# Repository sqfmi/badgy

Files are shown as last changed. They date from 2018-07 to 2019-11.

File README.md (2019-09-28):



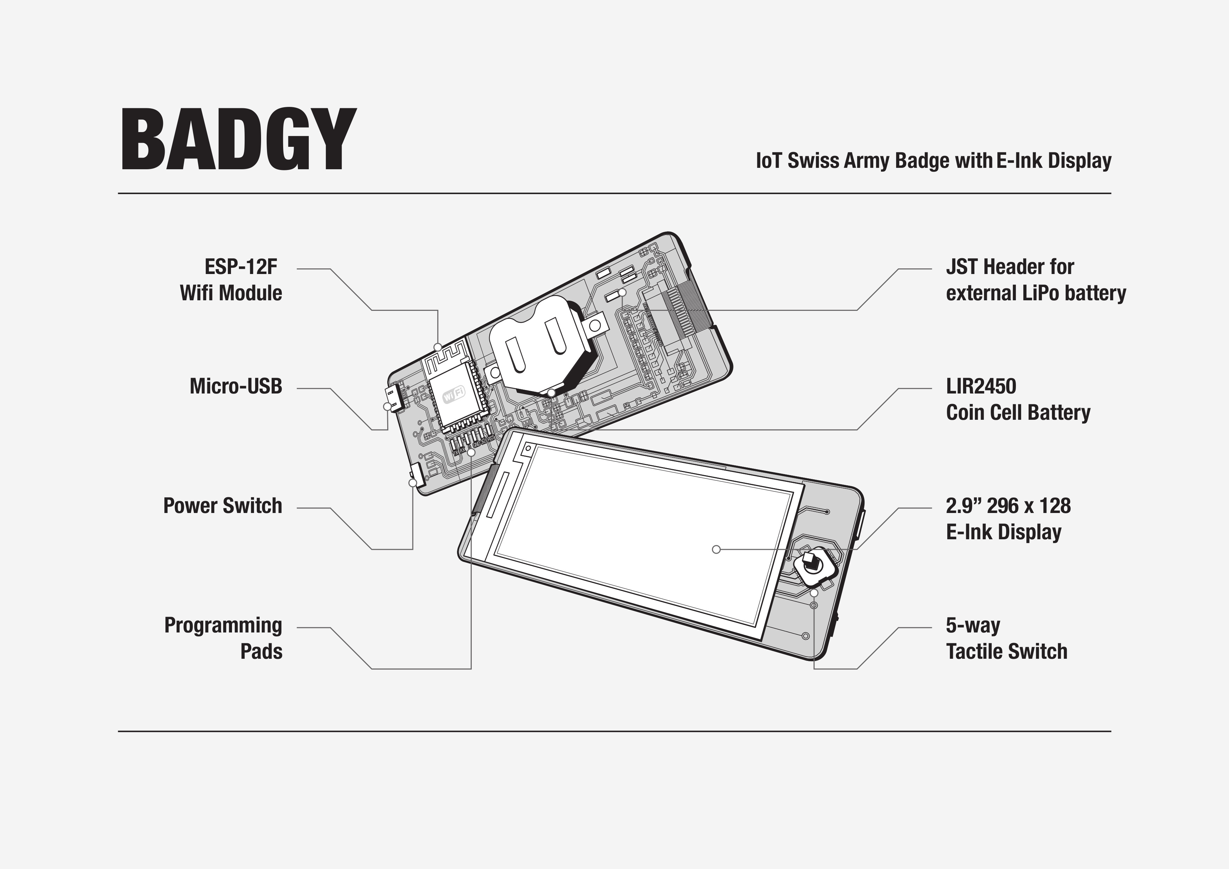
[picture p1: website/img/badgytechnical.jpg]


# Know Your Badgy

Since launching the first revision of Badgy, we have made various updates and fixes to the hardware and design. Refer to the diagram below to know which revision of Badgy you have. This is helpful for getting started and troubleshooting.

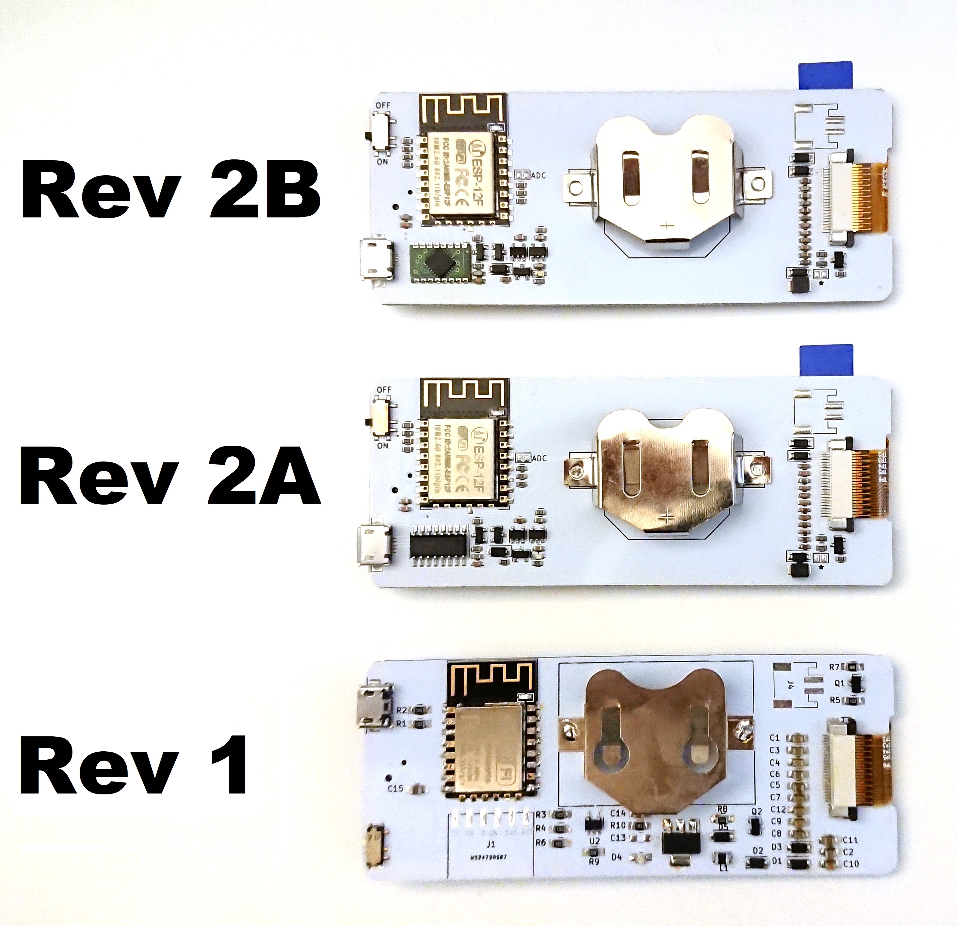
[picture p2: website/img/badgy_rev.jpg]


### Rev 2C

This is the latest revision of Badgy (September 2019) with a new display that supports 2-bit 4 color grayscale (Black/Dark Gray/Light Gray/White). It can be uniquely identified by the closed solder jumper on the back marked with the asterisk \*. It also has a green tab on the screen protector film.

### Rev 2B

This revision of Badgy (May 2019) can be uniquley identified by the small green PCB on the bottom left corner. It supports programming over USB (updated from CH340 to CP2104, woohoo!) and WiFi OTA. It fixes the battery issue with Rev 2A.

### Rev 2A

This revision of Badgy adds USB programming capability with the CH340 USB-UART controller. It also has two additional jumper pads: 1) ADC broken out if you choose to measure the battery voltage 2) jumper pad for driving other E-ink displays (e.g. 2.13" flexible E-ink). This version has a hardware bug that causes Badgy to not work on battery power, full description with hacks/fixes described here https://github.com/sqfmi/badgy/issues/20.

### Rev 1

This is the original and first revision of Badgy. It only supports firmware uploading via WiFi OTA, but the programming pads are broken out so you could also use your own USB-Serial adapter.

# Getting Started

By default your Badgy displays the welcome message when powered on. To upload new firmware, you can simply connect via USB **(Rev 2A/2B)**, or to your WiFi network **(Rev 1/2A/2B)**. You will also need a **LIR2450** rechargeable coin cell battery if you wish to run on battery power only.

**WARNING: Make sure you are using a rechargeable battery (LIR2450 coin cell or 1S LiPo). Other batteries such as the CR2450 or CR2032 are undervoltage (3.0V) and will not work. The battery charging IC also does not have reverse polarity protection! Check the polarity before inserting the battery**

## Over USB (for Rev 2A & Rev 2B)
1. Download and install the latest version of Arduino IDE
2. Install board support for the ESP8266 using the Arduino Board Manager using instructions found [here](https://github.com/esp8266/Arduino#installing-with-boards-manager).
3. If you are using a windows machine then you need to add support for the CP201X by installing drivers from [here](https://www.silabs.com/community/interface/knowledge-base.entry.html/2016/12/30/downloading_cp210xd-ek07).
4. The USB-Serial device should show up on the list of ports (e.g. COM8, /dev/cu.\* , /dev/tty.\*).  If you don't see it then it is possible that you need to install the drivers for CP2104 on your system.
5. From Tools -> Board choose "NodeMCU 1.0 (ESP-12E Module)".
6. Compile and upload one of our code samples, or create your own!  See the 'compiling' section below for some details.

Note that if the ESP chip is in a deep sleep then it will not automatically respond to the upload request and you may see something like "error: espcomm open failed" when trying to upload.  A manual restart of the ESP chip, using the power slide button, just prior to upload gives you a small window of time to upload.

## Over WiFi
1. Power your Badgy through USB or a rechargeable battery, or both. Make sure the power switch is in the off position (up)
2. Hold down the center button and slide the power switch on (down). **Note: On older firmware versions it is not necessary to hold down the center button and OTA is on by default**
3. The screen should now update letting you know to connect to the "Badgy AP" network. You can now let go of the center button
4. Using your mobile phone, connect to the "Badgy AP" WiFi network
5. Follow the captive portal instructions to select your desired WiFi connection
6. Once connected, Badgy is ready to receive new firmware! Go to http://*YOUR_IP_ADDRESS*:8888/update to upload your new firmware
7. WiFi credentials are automatically saved onboard, your Badgy will automatically connect to your selected network the next time you perform an update

Check out the examples folders for various code samples, we're constantly adding more!

## Compiling examples
The readme files within the example directories contain specific library and version information for that example.   At a minimum though you should consider installing the following libraries as they are very useful and/or necessary for any real functionality.

1. GxEPD library: you can find the repo [here](https://github.com/ZinggJM/GxEPD).
2. AdaFruit GFX library: installation instructions available [here](https://learn.adafruit.com/adafruit-gfx-graphics-library/overview).
3. WifiManager library: you can find the repo [here](https://github.com/tzapu/WiFiManager).  You can also find this in the Library Manager under 'WiFiManager by tzapu'.
4. Time library: you can find the repo [here](https://github.com/PaulStoffregen/Time).  
5. ArduinoJson library: you can find the repo [here](https://github.com/bblanchon/ArduinoJson). You can also find this in the Library Manager under 'ArduinoJson by Benoit Blanchon'.   Make sure that you install a 5.x version since some of the examples require that.

## Autoreset
Some users have reported that Badgy doesn't automatically reset after uploading a new sketch via USB; this appears to be an issue with the ESP8266 Arduino library v2.5.0+. You can either toggle the power switch to reset, or downgrade to v2.4.2. This issue does not affect the operation of Badgy

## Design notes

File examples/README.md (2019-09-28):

## Setup
- Install Arduino IDE https://www.arduino.cc/en/Main/Software
- Add ESP8266 Arduino Core using the Boards Manager https://github.com/esp8266/Arduino#installing-with-boards-manager
- Install the following libraries for the various examples
    - Adafruit GFX library https://github.com/adafruit/Adafruit-GFX-Library
    - GxEPD v3.x library https://github.com/ZinggJM/GxEPD
    - ArduinoJSON v5.x library https://github.com/bblanchon/ArduinoJson
    - WiFi Manager library https://github.com/tzapu/WiFiManager
    - Time v1.5 https://github.com/michaelmargolis/arduino_time
    - WebSockets https://github.com/Links2004/arduinoWebSockets
- When compiling the sketch in the Arduino IDE, choose **Tools** > **Board** > **NodeMCU 1.0 (ESP-12E Module)**    

## Uploading Your Own Firmware

### Over USB (For Rev 2A/2B)
1. Once the right board and port is selected, simply click upload and your sketch will be uploaded automatically. Make sure the power switch is on (down), and you should see the the blue LED on the ESP-12F module flsahing.

### Over Wifi (For Rev 1/2A/2B/2C)
1. In the Arduino IDE, go to *Sketch* -> *Export compiled Binary* to create your firmware binary `*.bin`
2. Slide the power switch off (up), hold the center button and slide the power switch on (down) at the same time. Your Badgy should now be in OTA mode.
3. Go to http://*BADGY_IP_ADDRESS*:8888/update to upload your new `*.bin` file
4. Badgy will now restart with your new firmware
### Note: If your new firmware does not include the WiFi and OTA code, you will no longer be able to update over WiFi!

## Converting Your Own Image
Badgy has a 296x128 black & white e-paper display, you can upload your own bitmap image.
1. Go to http://javl.github.io/image2cpp/ and upload your own image file
2. Resize the image so that it is within the dimensions of the display (works best if dimensions are multiples of 8 e.g. 72x64)
3. Select **Arduino code** under **Code output format** and click the **Generate code** button
4. Copy and paste the output into your code; you can create a new header file (e.g. myimage.h) or simply replace the ```hello.h``` file in the Hello example. Remember to include the file in your main sketch.
5. The method ```display.drawBitmap(image, 0, 0, 296, 128, GxEPD_WHITE);``` draws the bitmap on the screen. The parameters are in the following order: image byte array, x, y, width, height, and background color. Call ```display.update()``` after to draw the new image.

## Restoring To Default Firmware
1. Download the default firmware [badgy.bin](https://github.com/sqfmi/badgy/raw/master/examples/badgy.bin)
2. Slide the power switch off (up), hold the center button and slide the power switch on (down) at the same time. Your Badgy should now be in OTA mode.
3. Go to http://*BADGY_IP_ADDRESS*:8888/update and upload `badgy.bin`
4. Badgy will now restart with the default firmware
5. You can also do this over USB following the instructions from above

## Using MicroPython with Badgy
Check out our [badgy-python repo](https://github.com/sqfmi/badgy-python)

## Manual Flashing / Recovery (For Rev 1)
* If for some reason your code is crashing and OTA updates isn't working, or if you prefer uploading over serial, you can manually flash the firmware using the programming pads on the PCB. Using a USB-Serial adapter (e.g. FTDI), connect the pins to the pads like so:
```
WARNING: ALWAYS DISCONNECT OTHER POWER SOURCES (E.G. USB/BATTERY) BEFORE CONNECTING SERIAL ADAPTER TO THE PROGRAMMING PADS.
WARNING: AVOID CONDUCTIVE CONTACT (E.G. METALS/LIQUIDS) ON THE EXPOSED PADS TO PREVENT DAMAGE
+------------+-----------+
| USB-Serial | Badgy     |
+------------+-----------+
| RX        =>    TX     |
| TX        =>    RX     |
| GND       =>    0      |
| GND       =>    GND    |
| 3V3       =>    3V3    |
| NC        =>    RST    |
+------------+-----------+
```
The blue LED on Badgy should start blinking during upload. You can use the Arduino IDE or [esptool](https://github.com/espressif/esptool) to flash your firmware.

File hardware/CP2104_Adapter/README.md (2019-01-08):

This is an adapter board to replace the CH340C with a CP2104. We recommend 1.0mm PCB thickness or less.

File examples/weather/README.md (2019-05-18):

# Weather Station

This code sample demonstrates a simple weather station that displays the current & forecasted weather using the [openweathermap](https://openweathermap.org) APIs.

Note that because this example puts the ESP into a deep sleep if you want to reprogram it via the USB then you have to manually stop and restart it using the slider switch at the moment just prior to the upload starting.

## Required Libraries
- See the base required libraries in the root Readme for this repository
- GxEPD 2.x
- ArduinJSON 5.x
- Time 1.5.0 - You can find the repo [here] (https://github.com/PaulStoffregen/Time)).  

## Instructions
- Download code sample and required libraries, and compile/upload in the Arduino IDE (1.8.5)
- Sometimes the API will return an error if the service is unavailable, simply restart Badgy to try again

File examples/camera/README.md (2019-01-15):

# Badgy Camera

<p align="center">
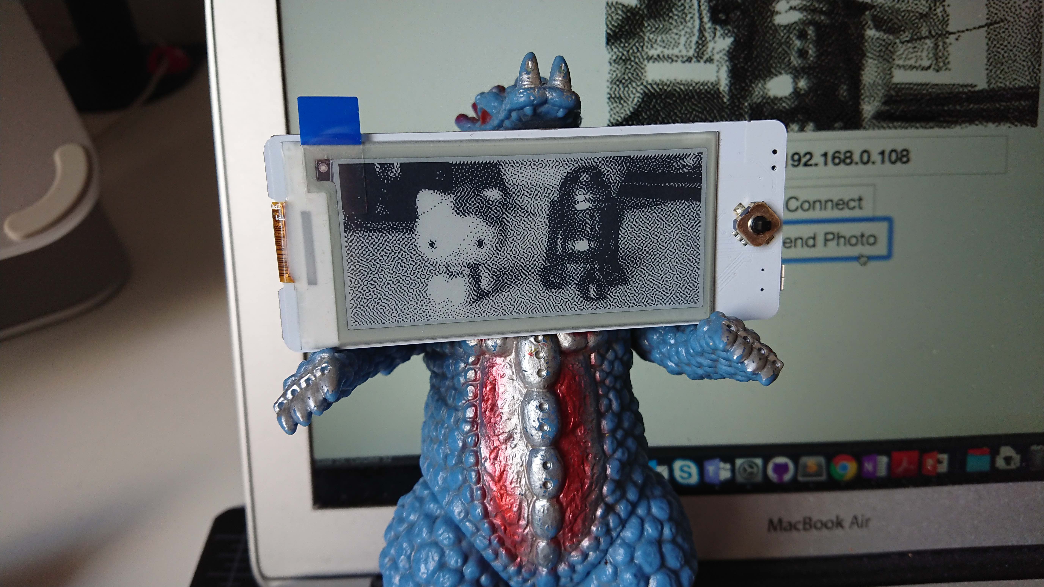
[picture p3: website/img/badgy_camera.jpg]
	
</p>

This code sample demonstrates display photos on Badgy captured through the webcam. Photo on the canvas is dithered and converted to a byte stream, then sent to Badgy over WebSocket. 

## Instructions
1. Turn on Badgy and wait for it to connect, note the IP address displayed.
2. Open `badgy-camera.html` using Chrome. The browswer will prompt you for camera permissions, click "allow".
3. Enter the IP address and click connect
4. Click "Send Photo" to capture and send the photo to Badgy

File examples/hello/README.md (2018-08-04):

# Hello Name Badge

<p align="center">
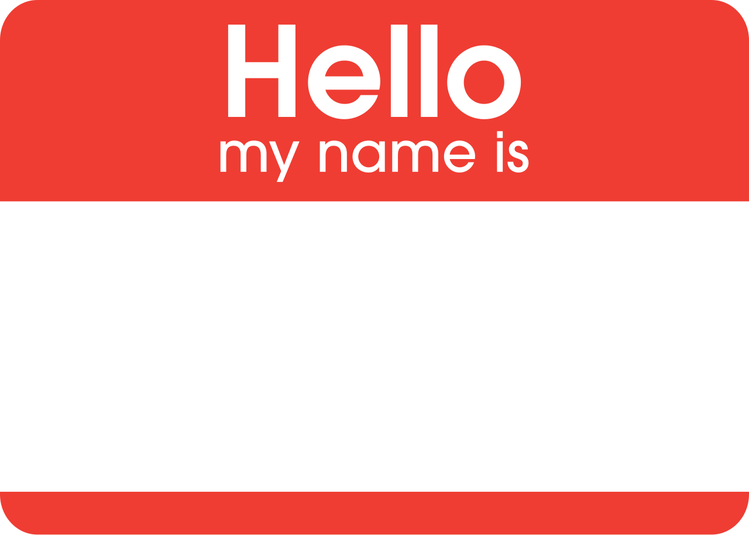
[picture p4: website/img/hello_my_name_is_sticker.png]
	
</p>
<p align="center">
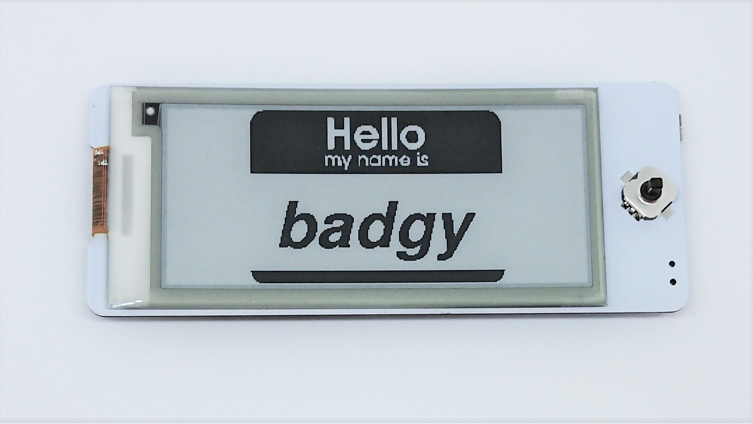
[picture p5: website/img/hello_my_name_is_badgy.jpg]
	
</p>

This code sample demonstrates displaying a "Hello my name is" badge on Badgy. The background image and is converted to a byte array from a PNG file and is stored in `hello.h`. The name is stored in a char array `const char* name = "badgy"` which can be changed to any text. It may be required to tweak the cursor location and font size in `showHello()` to perfectly position the text.

Power saving features are not enabled in this code sample and Badgy stays fully on. To conserve power, simply turn off Badgy as the e-paper display does not require power to maintain the displayed image.

## Instructions
- Download code sample & required libraries, and compile/upload in the Arduino IDE (1.8.5)
or
- Download the pre-compiled binary [hello.bin](https://github.com/sqfmi/badgy/raw/master/examples/hello/hello.bin) and upload using OTA

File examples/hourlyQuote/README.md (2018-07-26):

# Hourly Random Quote

This code sample demonstrates parsing JSON data from an API endpoint, as well as **deep sleep mode** for conserving power. To enter OTA mode, hold down **center** when powering on Badgy until the IP address is displayed. The code performs the following steps:

## Operation
1. Connect to WiFi on boot
2. If the **center** button is pressed, go into OTA mode (hold button till screen updates)
3. Otherwise, perform an `HTTP GET` request to the random quote API endpoint
4. Parse the returned JSON and display the quote
5. Enter deep sleep for approxmiately one hour
6. The sleep time can be modified at **line 59** in microseconds e.g. 60e6 = 60 seconds

## Instructions
- Download code sample and required libraries, and compile/upload in the Arduino IDE (1.8.5)
- Download the pre-compiled binary [hourlyQuote.bin](https://github.com/sqfmi/badgy/raw/master/examples/hourlyQuote/hourlyQuote.bin) and upload using OTA

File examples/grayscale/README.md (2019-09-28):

# Badgy Grayscale Demo

This code sample demonstrates displaying a 2-bit grayscale image (Black/Dark Gray/Light Gray/White). The image is converted to a byte array using the [Image2Lcd](https://www.waveshare.com/wiki/File:Image2Lcd.7z) tool.

<p align="center">
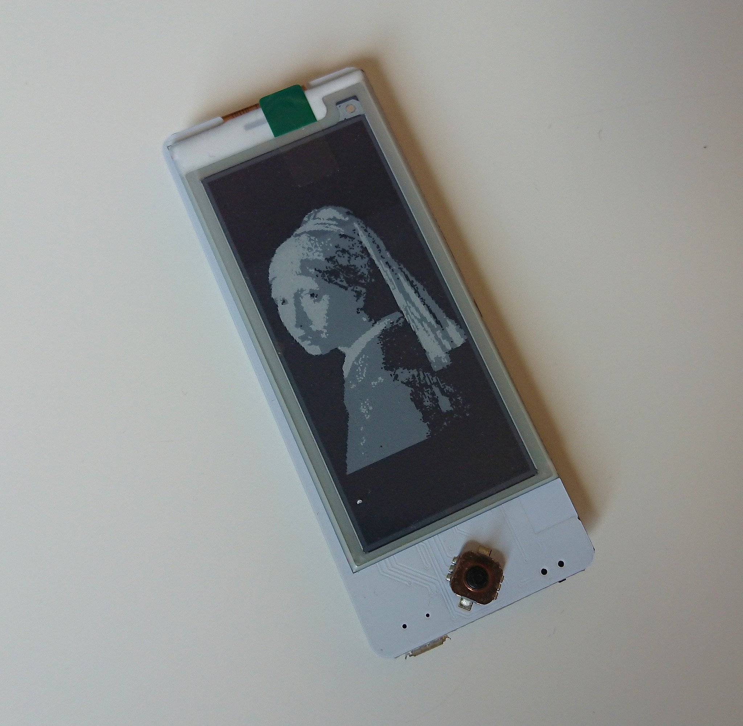
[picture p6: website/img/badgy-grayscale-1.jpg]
	
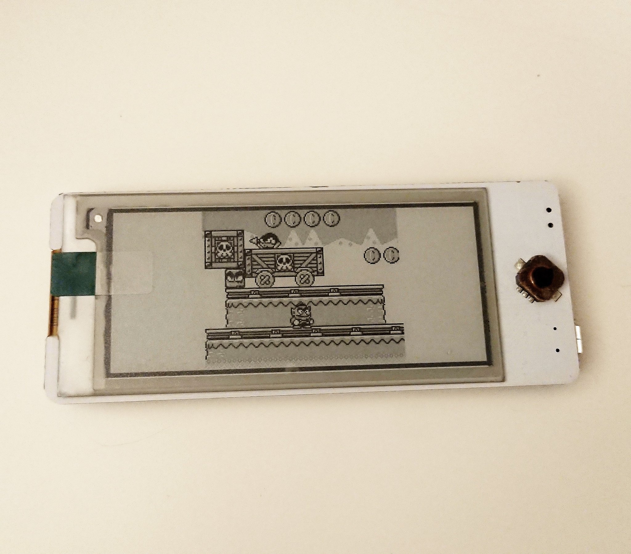
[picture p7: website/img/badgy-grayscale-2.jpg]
  
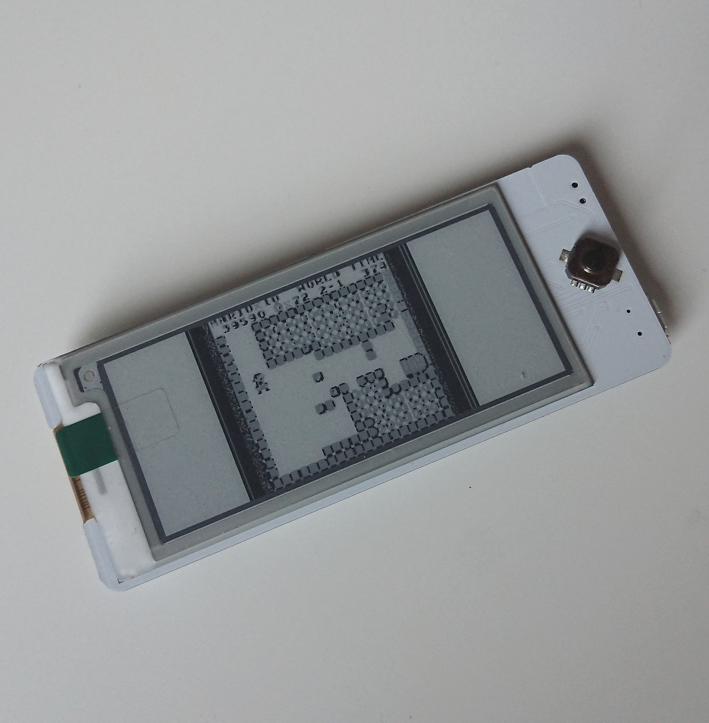
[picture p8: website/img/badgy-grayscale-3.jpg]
  
</p>

The following settings were used to generate the example images:

* Output file type: C array
* Scan mode: Vertical scan
*	BitsPixel: 16 Color
*	Max Width: 296
*	Max Height: 128
*	Scan Right to Left: Checked
*	Reverse Color: Checked
*	Mirroring: Normal

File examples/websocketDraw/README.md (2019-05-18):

# WebSocket Draw

<p align="center">
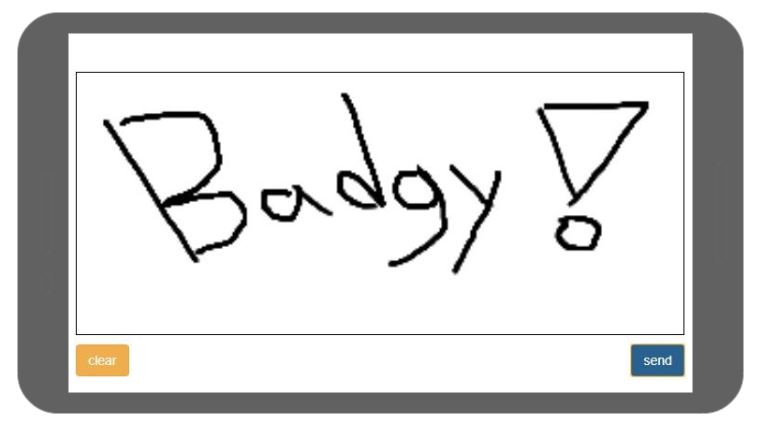
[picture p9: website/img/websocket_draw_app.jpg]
	
</p>
<p align="center">
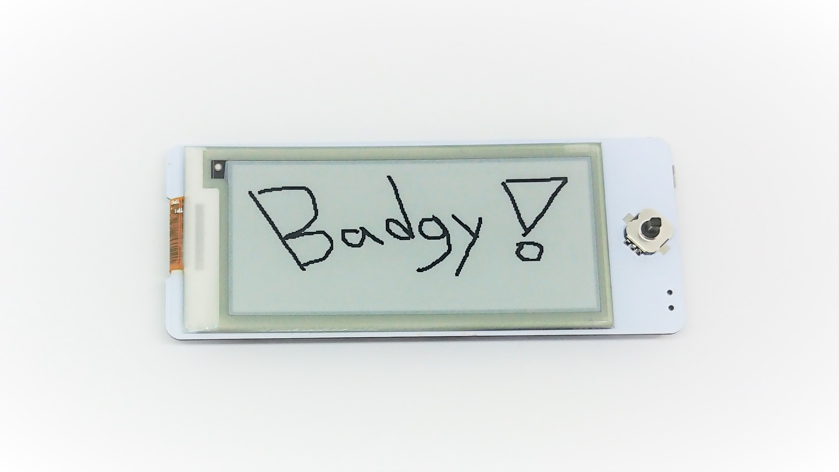
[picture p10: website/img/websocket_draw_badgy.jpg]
	
</p>

This code sample demonstrates drawing images on Badgy. Drawing done on the canvas is converted to a byte stream and sent to Badgy over WebSocket. 

## Required Libraries
- See the base required libraries in the root Readme for this repository
- Websocket server and client library found [here] (https://github.com/Links2004/arduinoWebSockets).
- ArduinJSON 5.x
- Time 1.5.0

## Instructions
1. Turn on Badgy and wait for it to connect, note the IP address displayed.
2. Edit `index.html` **line 58** and replace the IP address with Badgy's IP address e.g. `ws://192.168.0.113:81`.
3. Open `index.html` using Chrome or host it on a local server and open it on a mobile phone.
4. Draw on the canvas (using mouse or touch) and press **send**, your image should then appear on Badgy.
5. To clear the display, press **clear**

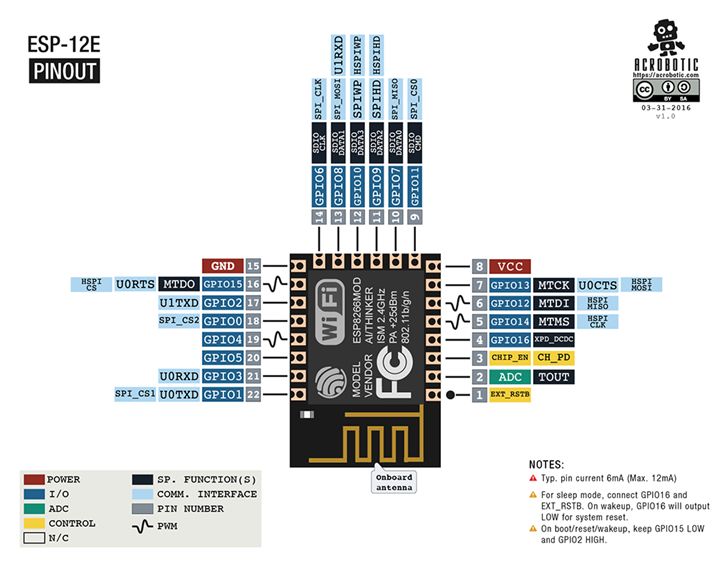
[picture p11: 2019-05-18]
hardware/ESP8266-12E.jpg

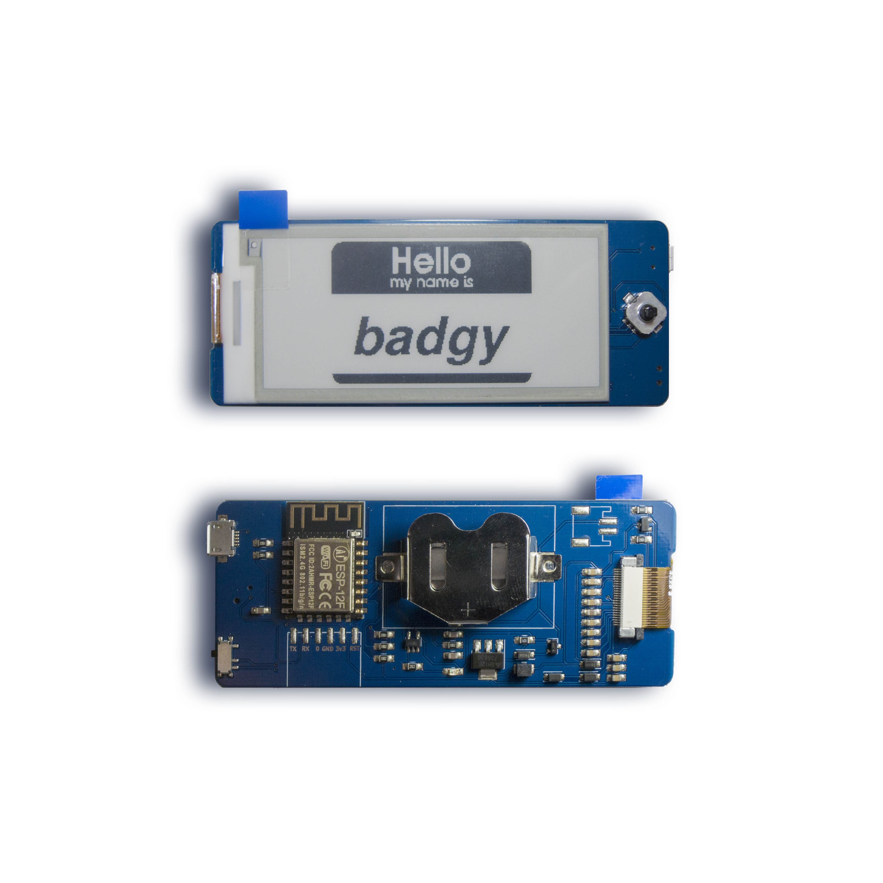
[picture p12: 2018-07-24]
website/img/badgy_stock_photo.jpg

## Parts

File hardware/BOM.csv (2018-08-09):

Designator | Package | Quantity | Value
R1,R2,R3,R4,R5,R6,R10 | 0805 | 7 | 10K
R7 | 0805 | 1 | 3
R9 | 0805 | 1 | 2K
R8 | 0805 | 1 | 100K
C1,C2,C3,C4,C6,C7,C8,C9,C10,C11,C12 | 0805 | 11 | 1uF
C5,C13,C14,C15 | 0805 | 4 | 4.7uF
L1 | 1210 | 1 | 68uH
D1,D2,D3,D5 | SOD-123 | 4 | MBR0520
D4 | 0805 | 1 | LED
Q1 | SOT-23 | 1 | AO3418
Q2 | SOT-23 | 1 | FDN340P
U1 | ESP-12 | 1 | ESP-12
U2 | SOT-23-5 | 1 | MCP73831
U3 | SOT-223-3 | 1 | AP1117
J2 | 24_Pins_0.5mm_Pitch_ZIF_Connector | 1 | 24_Pins_0.5mm_Pitch_ZIF_Connector
J3 | Micro_USB | 1 | USB
SW1 | Slide Switch | 1 | POWER
SW2 | 5-Way Tactile Switch | 1 | 5-Way Tactile Switch
BT1 | 2450 | 1 | Battery_Cell
EPD | 2.9inch 296x128 | 1 | https://www.waveshare.com/2.9inch-e-paper.htm

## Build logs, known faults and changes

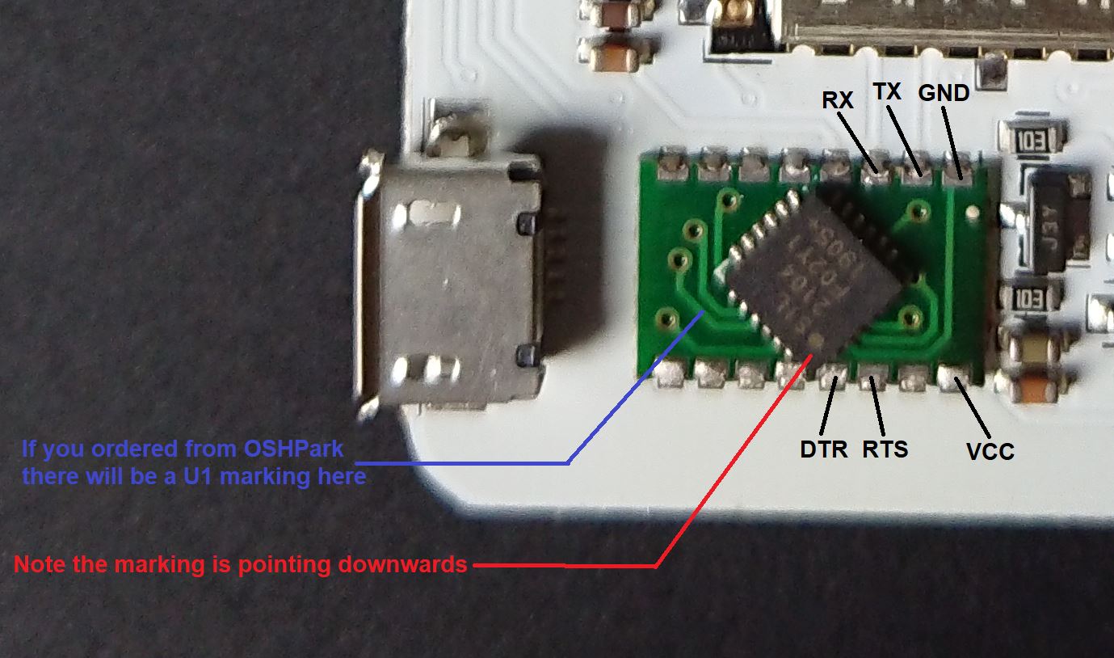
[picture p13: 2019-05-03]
website/img/badgy_fix_2.JPG

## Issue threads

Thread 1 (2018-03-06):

Pcb layout

mickae1, 2018-03-06:
Hi, can you give the pcb layout?
Or when are you planning to build other board?

MisterScience5, 2018-08-14:
If you are willing to share PCB layout files, I would also very much appreciate that:)

mstietencron, 2019-05-16:
Hi @sqfmi! We would love to fork your hardware design of badgy and would highly appreciate to get access to the PCB layout (and the rev 2B schematics)! Thanks!!

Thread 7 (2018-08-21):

3d CAD files for case printing?

lasniko, 2018-08-21:
I wanted to put my badgy in a nice 3d printed casing. Does anyone have a fitting 3d model?

chunkysteveo, 2018-08-21:
Would also like this when it arrives - was waiting on the board files to import into Fusion to then work from that. If you can wait till I get mine, and we get the board schematics - I can create one for you?

sqfmi, 2018-08-27:
We're trying to export the STEP file for the board but we're still missing some 3D models (e.g. FPC connector, battery clip, etc.) Once we have those created (or if someone can point us to where we can find them) we'll put it on GitHub right away

chunkysteveo, 2018-08-28:
Have you checked "GrabCAD"? It's a great user resource of 3D objects.

Pablo2048, 2018-08-29:
You can also try 3dcontentcentral.com , and/or http://www.pcb-3d.com/electric_type/ffc-fpc-flat-flexible-connectors/ ...

chunkysteveo, 2018-08-29:
This is probably what you need for your 5-way - https://grabcad.com/library/thmu-13-smd-joystick-it-1501-ts-1600e-1. Looks just the part?

chunkysteveo, 2018-08-29:
Actually fits perfect according to the holes in the PCB STEP file! Do you need the e-ink display creating, as that is missing?

sqfmi, 2018-08-29:
Yes and thank you for submitting the PR! The 3D model is now complete! 🍾

chunkysteveo, 2018-08-30:
Eeeek... now I should think about a cool case!?!

sanecito, 2018-09-07:
Nice! I had made one out of Legos as a placeholder case. If anyone designs a case for badgy (especially one that supports gluing magnets to the back) please link to it so I can 3D print it!

chunkysteveo, 2018-09-07:
I'm in the middle of designing some cases... all theoretical as I don't have the Badgy yet. So I guess the idea is to stick it to a fridge or something? Sounds cool! If I get time, I think I will make a few case versions (I just like to mess about in Fusion360!!) so a magnet version that sits flush is on the cards now! What size magnets, like the little 5/6mm circle NEO ones?

svenove, 2018-09-07:
> So I guess the idea is to stick it to a fridge or something?

I want to attach Badgy to my shirt, as a name badge. :) Magnets will probably be the best solution any way, with magnet on the inside of the shirt.

chunkysteveo, 2018-09-07:
Ah yes, magnets would work well too for clothing.

gwtzt, 2018-09-07:
Stephen,
I ordered one more than I need. I could send you one if you send me a matching case in return.
Regards,
Stephan

chunkysteveo, 2018-09-07:
Ah that's very generous of you! I have one coming my way, but the definition of "having one more than I need" does not compute for me!! hahaha! I'd be interested in a service swap though and could send a case out for a swap once designed and printed. Whereabouts are you in the World?

sanecito, 2018-09-07:
I use an Adafruit magnet that's about 45.3mm x 13.3mm x 5.1mm: https://www.adafruit.com/product/1170
I know some 3D print designs use holes in say, a wall of a box or what have you to save on material, weight, time, etc. So long as there's at least a chunk of back surface for all the adhesive for the magnet that would be fine for how I would use the case.

chunkysteveo, 2018-09-07:
That's a big magnet! I will take the dimensions though and take that on board.

Steve

svenove, 2018-09-07:
> I use an Adafruit magnet that's about 45.3mm x 13.3mm x 5.1mm: https://www.adafruit.com/product/1170

Since they charge 17$ for shipping, I'd rather try something like these:
https://www.aliexpress.com/store/product/10pcs-45-13mm-Wholesale-Strong-Magnetic-Name-Tag-ID-Badge-Holder-with-3M-Adhesive-on/3011056_32811317834.html

But, as @sanecito says - as long as there is a flat surface on the back, anything/any size can be attached by adhesive. :)

chunkysteveo, 2018-09-07:
Yeah, that's way cheaper! Lets just say there will be a 46 x 14 mm indent in the back to locate a bar magnet :)

sanecito, 2019-03-06:
@chunkysteveo Have you finished any of your case designs by chance?

chunkysteveo, 2019-03-07:
Hi @sanecito - I did do a test case for the original Badgy, which can be found in the still open Pull Request on this repo, you can find files to download in the comment thread. I'm not 100% happy, and it seemed a little over engineered for the task. But have not done a follow up design, yet. I did then create a more simpler "bumper" style case that can be used as a badge/lanyard too, and I have made it compatible with both the old and new versions of Badgy - this can be found here - [badge-frame_all_v3.zip](https://github.com/sqfmi/badgy/files/2460886/badge-frame_all_v3.zip). Due to all the issues with the new Badgy serial and battery problems it's not been something I have been pushing myself to do. There are some designs on Thingiverse too, which I will eventually put mine on there too.

Steve

Xaldimo, 2019-05-18:
There is also a case on Thingiverse:

https://www.thingiverse.com/thing:3312442

chunkysteveo, 2019-05-22:
My bumper case(s) are now on Thingiverse https://www.thingiverse.com/thing:3647429

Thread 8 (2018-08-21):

Can't upload to device

PlastiBots, 2018-08-21:
Hey guys..  Cool device here.  Looking to hack it into a weather unit.  I followed  the instructions to get it on my WiFi and that works.  However, now I can't seem to access the device or ping it.  When starting I hold the center button and power on. Then get to the "_you are now connected....   go to 192.168.2.44:8888 to upload a sketch_". However, when I go to that IP in Chrome I get nothing - cant find it.  Ping also does not work.  The device shows on my router as connected and has a strong wifi signal.  Any ideas?  Note that I am powering via the PC USB cable.  Also no port shows up in Arduino IDE.  Am I correct that this does not support upload via USB as I see no USB/TTL converter on board?

Details:  Win 10.  Arduino 1.8.5.  All libraries installed and compiling fine.  Choose Generic ESP8266 module.   Followed instructions here: https://github.com/sqfmi/badgy.  Also note that I tried this all with a 2A power supply as well, so the unit is sufficiently powered.

Q: When compiling, what board should be selected?

sqfmi, 2018-08-22:
Hi @PlastiBots!

Do you know if your computer and Badgy are both on the same network/subnet? If they are you should be able to connect and upload over OTA. Check for any settings on your computer/router that may be block port 8888. You can choose the board "NodeMCU 1.0 (ESP-12E module)" with all other settings at default for compiling.

Let us know if this works, thanks!

PlastiBots, 2018-08-22:
Hey.  I figured it out.   I had to enable UPnP on my router.  Once I did that, I was able to access the page.

sqfmi, 2018-08-22:
Awesome! Thanks for letting us know the solution, we'll add it to our troubleshooting guide.

PlastiBots, 2018-08-22:
Hey guys.. Spoke too soon.  Oddly, tried again today and it's failing again - even with UPnP on.  I think it's an issue with my router/UPnP as it definitely worked when I first turned it on.  I've tried turning it off, then back on but it still fails.  Will keep plugging away and report back.

vidax, 2018-09-19:
Okay, it is a badgy issue. Am working with Epeejunior, and his Badgy does not want to connect, so i pulled another badgy from the stack and it connects successfully to the same network. We even tried to renew the lease of the badgy on the router and the badgy showed a new IP, but still, no way to connect. So I do not think it is a network issue, but really a bug.
I will try to connect this badgy at home (It will ask me to setup a new wifi). if it does not work, I will flash it via FTDI and report here.

sqfmi, 2018-09-20:
Thanks @vidax, please let us know the results.

vidax, 2018-09-20:
I turned on the badgy on another network. This time, the badgy does not refresh the screen and is stuck on telling me to login on the IP address of the other network.
--> If I go back on the old network, the screen will refresh, show the same screen, or a new IP if we canceled the lease, but still no way to connect.

sqfmi, 2018-09-20:
When trying on another network, try holding the center button for at least 15 seconds after powering on. The WiFi manager will try a few times with the saved credentials, before it times out and starts the Badgy AP again to ask for new credentials.

Can you also confirm that the IP/Ports are not blocked on your PC/Router/Network? Try hosting a WiFi hotspot with your phone and see if you are able to connect. It does sounds like a networking issue so far, please do let us know your testing results so we can try to support, thanks!

sqfmi, 2018-10-06:
Closing. Please re-open if issue persists.

Closed 2018-10-06.

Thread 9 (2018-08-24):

Wake from DeepSleep with button?

svenove, 2018-08-24:
Is there any way to wake Badgy up by using the switch, when using ESP.deepSleep()?
Like if I want the HourlyQuote-example to also update when I press the button. :)

sqfmi, 2018-08-25:
Hi @svenove! Unfortunately no, the ESP8266 does not support GPIO interrupts to wake from deepsleep. The only way to wake the ESP8266 is to perform a power cycle (e.g. slide the power switch up and down) or by pulling the reset pin low.

svenove, 2018-08-25:
@sqfmi That’s what I thought, hmm...
What battery life can be expected when always awake? Like in the Spotify-example. I would expect that not using deepsleep has a huge impact on battery life?

gordonendersby, 2018-08-25:
Would be great if you could break out the reset pin or have pads that a momentary switch could be soldered on to.

In the meantime you could add your own push switch to the reset pin with a bit of careful soldering.
and mount the switch on whatever you are housing the badgy in.

svenove, 2018-08-26:
I guess calling wifi.stop() would reduce power consumption? At least if not reconnecting too often (as reconnect probably uses a bit more than keeping connected?).

So instead of deep sleep, I could disconnect from WiFi instead?

Any other tips for reducing power consumption? :)

sqfmi, 2018-08-26:
Instead of deep sleep, you could also try "light sleep" mode which still allows you to wake on interrupt, and consumes ~1mA  (according to documentation. Check out this thread for some code snippets and details: https://github.com/esp8266/Arduino/issues/1381

Closed 2019-05-18.

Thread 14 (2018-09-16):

Is the Badgy supposed to charge the battery?

vidax, 2018-09-16:
I have the LIR2450 loaded in the badgy, and when I plug the USB, I see a red light in the back.
I am wondering if the badgy is able to charge the battery because when I remove the USB after a few hours, the badgy does not seem to work on battery.

sqfmi, 2018-09-16:
Hi @vidax,

The USB should recharge the LIR2450 battery. Please ensure you have the battery inserted in the correct polarity, and the battery has been sufficiently charged (3.7V - 4.2V).

chunkysteveo, 2018-09-25:
Ahh crap....! ...and with that I released some magic smoke from the MCP73831 charge IC! 👎  Was probing around from the USB V+ and touched the VDD of the chip and it went "pooof" (was plugged in to USB at the time). I have some spare MCP73831 circuits, I may try to de-solder and re-apply one.

While poking about looking at the schematic and the PCB layout - I did notice that the LED D4 which is the charge state LED has a current limiting resistor of 2K Ohm. Should this not be more in line with common LED resistors, and the spec sheet, around 200-470Ohm? Or is this high to work with the High-Impedance state of the STAT line as well as Hi and Low?

sqfmi, 2018-09-25:
Sorry to hear that @chunkysteveo :( Yes you can replace it with an off the shelf MCP73831; we chose 2K Ohm simply because we found the LED to be too bright!

chunkysteveo, 2018-09-25:
Ahh OK, makes sense for the LED. I will try a new MCP73831 to fix this one, and test with a number of LIR2450's I have. Hopefully was just the IC that was dead (well it is now!!! :)  )

Closed 2019-05-18.

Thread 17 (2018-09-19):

Board will not go into OTA mode

patrickdijusto, 2018-09-19:
I got the board working just fine out of the box.  I downloaded all the files needed to run "Hello".  I compiled it and uploaded it just fine.

But now the board will not return to OTA mode.  I shut it off, press and hold the center button, turn on the board, and nothing happens.  The edisplay still shows the "Hello my name is..." graphic.

I have tried this while powering the board via USB from my laptop, and via USB from a fully charged power brick.  When I flip the board's switch to ON, a red LED at the center of the lower edge of the reverse side of the board blinks about once every 7 seconds, in sync with the blue LED on the ESP32.  That's all that happens.

When I flip the switch to OFF, the red LED at the center of the lower edge of the reverse side of the board blinks about 5 times per second. THe blue light does not blink at all.

I have tried multiple USB cables and power sources.  Nothing works to put the board into OTA mode.

I do not have the skills to solder connectors to the board. What can I do?

patrickdijusto, 2018-09-20:
The screen does NOT refresh when I flip the switch from on to off or off to on.

I used the hello program from this git repo.  The only thing I changed in the hello program was my name.

sqfmi, 2018-09-20:
Thanks for the info. Could you share with us the compile settings used in Arduino? The blue LED on the ESP blinking every 7 seconds means it is crashing and resetting. Since the name is the only change to the code you made, it is likely to be either a compile settings error, or a hardware related issue (e.g. insufficient USB power, loose display connector, shorted components, etc.)

To flash your Badgy with a USB-Serial adapter, follow the wiring information in our [documentation](https://github.com/sqfmi/badgy/tree/master/examples) and push the pin headers against the board like so (you may have to scrape the surface a little for better contact):

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

sqfmi, 2018-10-06:
Closing. Please re-open if issue persists.

Closed 2018-10-06.

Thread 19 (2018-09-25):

How to use it... as a badge

titimoby, 2018-09-25:
The project is amazing, I really like it.
But I don't see on pictures how it is supposed to be fixed.
Any holes usable?

chunkysteveo, 2018-09-25:
A 3D case would be ideal to have this wrapped in. With space for a magnet, and loop for a lanyard... watch this space! (but yeah, a hole in the PCB would have been super handy!!)

chunkysteveo, 2018-09-27:
[case_prototype_badgy_frame.zip](https://www.chunkymedia.co.uk/wp-content/uploads/2018/09/case_prototype_badgy_frame.zip)
Try this one @titimoby  - not printed yet, but if you have a 3D Printer, feel free to try it out.

titimoby, 2018-09-27:
I'll give it a try... as soon as I get my badgy (waiting for paycheck ;) )

richardvk, 2018-09-28:
I did a quick print this morning, turned out nice! I did need to cut a tiny bit away from the top left diagonal so i could squeeze the board in, but otherwise good!

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

chunkysteveo, 2018-09-28:
Wicked. And yes - I have just printed one out too and can't get it to "squeeze" into the last corner. I thought there would be enough wiggle room, but no. I will adjust the "top left" corner to be less to it will be small enough to push in, but still grip it a little. This frame can be the "flexible" version, as I am sure it will fit fine with some Ninja Flex or TPU type material... version 2 to do!

chunkysteveo, 2018-10-08:
Have made a new version of the Frame (frame) which should be easier to insert the Badgy to as it has a "lip" in the top left that should allow you to snap the Badgy into. Also made it compatible with both versions of the Badgy (Blue and White PCB versions) as the USB/switch actually switch over top to bottom, and the ESP chip has moved.

To insert, locate Badgy into the "right" two corners, then twist the frame into the bottom left corner, and the top left corner should snap in... printing tonight so not tested yet...

[badge-frame_all_v2.5.zip](https://github.com/sqfmi/badgy/files/2455392/badge-frame_all_v2.5.zip)

richardvk, 2018-10-08:
Thanks Stephen!

I will give this a go asap :)

On Mon, 8 Oct 2018 at 19:33, Stephen Ludgate <notifications@github.com>
wrote:

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

chunkysteveo, 2018-10-09:
Ignore V2.5 above, try this version, especially if you have a new White PCB version.
[badge-frame_all_v3.zip](https://github.com/sqfmi/badgy/files/2460886/badge-frame_all_v3.zip)

veggie2u, 2018-12-24:
@chunkysteveo are you able to upload a model file that can be edited? I wanted to make a version that had both tabs with the holes on the top.

chunkysteveo, 2018-12-24:
It's a Fusion360 project,  if that works for you? Or i could make the alterations for you if you want?

veggie2u, 2018-12-24:
Oh, cool. I am trying to learn 360 right now.

veggie2u, 2019-01-04:
@chunkysteveo don’t mean to pester, but are you able to post the 360 project?

chunkysteveo, 2019-01-04:
Hi @veggie2u - the 360 project is a mess, and not something I would like to publish, especially if you are learning it(!!) Took me about 30 seconds to make the attached STL file with clips on the top - let me know if that works for you? - Steve

[badge-frame_v3_top_top.zip](https://github.com/sqfmi/badgy/files/2726303/badge-frame_v3_top_top.zip)

chunkysteveo, 2019-01-04:
Apologies for the slow reply too - been busy with Christmas, New Year etc and not been around many computers.

veggie2u, 2019-01-04:
@chunkysteveo That's cool. I get it. So I did print it, and it looks like the switch opening got filled in. I went back and looked in PrusaControl and in Slic3r and sure enough, the stl doesn't have the opening.

chunkysteveo, 2019-01-04:
Ahh crud! Let me check the file!

chunkysteveo, 2019-01-04:
[badge-frame_v3_top_top_fix.zip](https://github.com/sqfmi/badgy/files/2728503/badge-frame_v3_top_top_fix.zip)

Sorry about that, here's the correct file with the updated gaps for the switch and USB! Sorry you had to print it before spotting it!

Steve

veggie2u, 2019-01-05:
It printed just fine. Thanks!

lasniko, 2020-01-10:
I recommend printing in some flexible filament, since it makes attaching the badgy much easier.
Here is the one I printed in nylon:
[badgy name tag case.zip](https://github.com/sqfmi/badgy/files/4044825/badgy.name.tag.case.zip)

chunkysteveo, 2020-01-10:
Saw your post for the badge, nice neat case! Like the use of partial refresh too! :)

chunkysteveo, 2020-01-10:
...and printing in nylon..... hat off to you!!!

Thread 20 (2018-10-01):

Works with USB power, not with battery?

codepope, 2018-10-01:
Set up badgy on USB power, things behave as expected. Board LED glows flickers blue. Board boots up.

Popped a LIR2450 in with no USB connection and... nothing. Won't wake up, won't reset for new sketches, no LEDs glowing.

Pop in USB with LIR2450 in place, board LED glows bright blue (charging?) and board functions.

Any suggestions as to trouble shooting this?

chunkysteveo, 2018-10-01:
Just received my new (WHITE PCB) version and can echo the same here - Works fine on USB, appears to charge when an LIR2450 is in place (blue LED) and USB plugged in. Can switch on with an LIR2450 and USB connected, and interestingly when I disconnect the USB while still on it still works. Switch off and back on with just the LIR2450 and no power.. Have not looked into testing where power getting to, and also just testing another LIR2450, but this is odd behaviour indeed!  It's like the USB connection trips it on, and without that initial USB trigger, it doesn't power up?

@codepope  - if your board is working with both USB and LIR connected, disconnect the USB and does it still work on the battery? And then when you switch off and on, does it then fail to boot up?

Would be worth people advising which boards they have, I.E. I now have a blue PCB version with programming headers, and now a super cool white PCB with a serial-USB programming chip on the USB (very cool additon!)

codepope, 2018-10-01:
That's *exactly* what I'm seeing. (White PCB too). USB+LIR boots, pull the USB, it carries on running, then switch off and back on and it fails to boot up.

chunkysteveo, 2018-10-01:
hmmmm, maybe the power regulator is not detecting the battery voltage to switch on? Trying another battery here, but sounds like a valid problem.

codepope, 2018-10-01:
Seems to be another symptom - when you do the switch on with USB and then pull the USB the default sketch reports multiple incorrect directions selected when the stick is touched. Plug the USB back in and it reports as normal.

chunkysteveo, 2018-10-02:
Yes(!), did not notice that, but now also seeing that the button message reports randomly when going from USB to BATT, and it tends to report multiple button presses, and incorrect ones. It's actually reporting multiple presses as I type this and I am not touching it. Sounds like the button is not being de-bounced correctly, or something to do with the ground - unless on USB which may be grounding things correctly?? Could also tie in with the battery issue, maybe there is an incorrect ground issue when running on battery, so it won't boot up from battery?

chunkysteveo, 2018-10-04:
@sqfmi - any thoughts on this odd behaviour of the new boards? Noticed the use a new charge IC too, the TP4054.

Flet, 2018-10-05:
Same exact issue here :(

New white PCB. Tried two different fully charged batteries.

@sqfmi any thoughts?

chunkysteveo, 2018-10-05:
Oh ho.... Huston, we have a problem..! 😣

sqfmi, 2018-10-06:
Sounds like it could be a hardware issue with the new batch, let us investigate the issue and get back to you guys shortly.

chadvavra, 2018-10-06:
I just received 2 white PCB units and can also confirm that they do not boot, or even power the esp on battery power.

sqfmi, 2018-10-07:
Brief update, it seems while on battery power only, you are able to turn it on by resetting it. This can be done by using a metal object to short the reset pin with the metal shield (e.g. paperclip, key, etc.):

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

Hacky solution for now, will continue to diagnose the root cause.

codepope, 2018-10-08:
Doesn’t seem to be working for me.

chunkysteveo, 2018-10-08:
I can confirm this hack works for me and boots the ESP8266 on battery power.

A better connection to "tap" @codepope would be the **lower** pad of the Lipo JST connection (which is ground). Not the upper pad as that is the positive to BATT. The casing didn't seem to give a good reliable ground connection, but turn on the switch, put a wire (I used a dupoint breadboard wire) on the RESET pin imaged above, and then tap the lower JST pad - the ESP should flash it's blue light on boot. (don't tap the left side pads of the JST connection, these don't seem to be tied to ground, just mechanical fixings)

codepope, 2018-10-08:
@chunkysteveo Yes, the JST pad is easier to tap, but still no joy. To ensure I was getting a reset, I applied USB power and ground tapping the reset line did reset.

chunkysteveo, 2018-10-08:
hmmm, not good. Assume battery is fully charged too? Some flake-y issues going on to be sure! Hopefully there will be a fix soon, even if it's a bodge wire fix...!?

codepope, 2018-10-08:
Well, I thought it was, but testing says otherwise. Tried another battery which shows charged and it didn't play ether.

bmv437, 2018-10-09:
As a temporary fix, I added a reset button between the ground pad on the JST connector, and the RST pin on the ESP8266. Also threw on a JST connector and LiPo battery since I didn't have a proper coin-cell size LiPo.

Now I just power it on, and click the reset button to boot the ESP8266.

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

chadvavra, 2018-10-10:
I put in a LIR2045 and tried the bodge wire with no luck.  It does work with the USB power though.

sqfmi, 2018-10-10:
@Korenchkin yes! Thank you for the reminder :) The new schematic is in the hardware folder now.

Everyone else, sorry we're still trying to debug the issue :(

Korenchkin, 2018-10-11:
thanks for the schematic!i tried to find the problem,but this makes my head hurt..everything seems okay for starting,i'd try pulling the usb chip and stick with prog header(i'm guessing some leakage to ground),but maybe somebody will make smarter solution..like cap on reset?tried that,but did not work for me..but at least i know what the switch switches...

sqfmi, 2018-10-11:
Removing the CH340C does seem to work! But the reason is unclear at this point... we'll try to do some further investigation with a scope.

chadvavra, 2018-10-11:
I would like to go on the record as saying that the CH340 is the devil's brood.

I flipping hate those things

bmv437, 2018-10-11:
@sqfmi If you're looking for cheap alternatives to the CH340, I'm a big fan of the SiLabs CP2104. Adafruit uses them for all their newer dev boards. High data transfer rates, better driver support than the CH340, and cheaper than an FTDI.
Adafruit has more details on their product page: https://www.adafruit.com/product/3309

Korenchkin, 2018-10-11:
Just a theory,could the ch340 be pulling down gpio0 and/or reset over the 2 transistors?maybe only on start befor it semi-charges its vcc cap?then there are only rx/tx pins,they should not do anything high or low,and that seems all the influence it can do powered off

ibuildrockets, 2018-10-17:
@sqfmi Hmm.. Reset didn't work for me - the LED on the ESP8266 blinks when reset - but nothing. In fact, I get absolutely nothing happenng now :( sketches won't upload and the currently loaded sketch (weather) won't refresh :,( Oh, and the circled component is scortching hot -
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

chunkysteveo, 2018-10-17:
Can you upload a sketch via the USB 2 serial?

g2rHP7prvJqO, 2018-10-17:
> Removing the CH340C does seem to work! But the reason is unclear at this point... we'll try to do some further investigation with a scope.
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
sqfmi, 2019-01-02:
Sorry about the delay, we've had trouble finding a fab that could mass produce the CP2014 adapter boards for us. We're in discussion right now with a promising vendor at the moment. We'll keep everyone posted on any new updates and an ETA when it becomes available.

chunkysteveo, 2019-01-07:
That's good, was worried that the project had been abandoned. Do you have the board files available (the add-on board) for anyone that would like to make the CP2104 themselves?

chunkysteveo, 2019-01-08:
Brilliant, i'm sure it will help a lot of guys out. I may even try and solder one up...!

chunkysteveo, 2019-01-08:
Only just spotted your link to the original board project on Oshpark, I could have used that link, apologies!!

Just out of interest, does anyone know the difference between the CP2104-F03-QFN and the CP2104-QFN? Assume the F03 is a new version, as the "non" F03 chips are cheaper?

ibuildrockets, 2019-01-14:
I've just ordered the PCB from OHS Park - What's the difference between CP2104-F03-**GMR** and CP2104-F03-**GM** - does it matter? Just wanting to get the IC on the way, too :)

sqfmi, 2019-01-15:
They are the same part, the difference is just in packaging (**R** stands for reel)

jcaron23, 2019-02-15:
Hi all,

Are the boards currently sold on Tindie still suffering from this issue, or have they been updated?

Thanks!

sqfmi, 2019-02-28:
@jcaron23 all new boards will come with the CP2104 instead of the CH340C, which does not have the battery issue.

FYI we found a fab to create the adapter boards for us, we are now waiting for the CP2104s to arrive so we can begin testing it out. If they work ok, we will be offering them to those who were affected by the issue.

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

chunkysteveo, 2019-02-28:
Awesome news!!

MarquisdeGeek, 2019-03-15:
Is there any alternate fix for those of us with the old board, as shorting the reset pin didn't work for me?

chunkysteveo, 2019-03-15:
What's the difference between the  CP2104-**F03**-QFN and the CP2104-QFN?

@MarquisdeGeek - you can snip the VCC pin of the CH chip to disable it. You will lose the ability to program it via USB though.

MarquisdeGeek, 2019-03-18:
@chunkysteveo - Thanks, but that's a bit drastic for me!

emanuelstanciu, 2019-04-03:
@sqfmi Hi, I have one of the blue PCB models which was bought late last year and I suffer from exactly the same behaviour as described on this post. Any idea what's happening?
Works fine on USB power, but on Battery simply flashes the ESP blue LED and the nothing happens.
Any pointers are greatly appreciated

chunkysteveo, 2019-04-04:
@emanuelstanciu  -  I would recommend starting a fresh issue with this problem. This issue is related to the USB to serial chip not allowing the ESP8266 to boot when on battery. The blue PCB version does not have any USB to serial chip, so whatever issue you are seeing, it isn't to do with this issue. I don't want your issue to be lost in this bigger post!

If the blue light flashes, that would indicate that it has booted and is powered. Something else is not working here?

Steve

pingywon, 2019-07-24:
Any resolution here? I just got my badgy and was under the impression that the white REV B board did not suffer from this problem. I just got some fresh batteries and Badgy doesnt work at all on battery power.

Can someone please advise.

sqfmi, 2019-07-24:
Hi @pingywon, are you using LIR2450 batteries?

pingywon, 2019-07-24:
Not exactly. I have CR2450s

sqfmi, 2019-07-24:
You must use the LIR2450. The CR2450 is not rechargeable, and is also not the right voltage (3.0V), Check out the README for more details.

pingywon, 2019-07-24:
OK Great. So My original assumption that the issue has been resolved in my Badgy is correct?

chunkysteveo, 2019-07-24:
Yeah, REV B does not suffer the power issue on battery when using a. LIR2450 rechargeable battery.

Carltk, 2019-07-25:
What ever happened to the offer from March 1 about the CP2104 adaptor boards. Do we have to do
anything to register our interest? I have 2 of the affected boards.

sqfmi, 2019-07-25:
Hey @Carltk, send us a message with your Tindie order number and we'll ship the adapter boards to your mailing address. Thanks!

Springwald, 2020-01-08:
I also have 2 badgys with this issue. Any chance to get the adapter boards? Thanks!

sqfmi, 2020-01-09:
Hey @Springwald, send us a message with your Tindie order number and we'll ship the adapter boards to your mailing address. Thanks!

MarquisdeGeek, 2020-01-09:
What is the preferred channel to send the message, since I also need an adapter board? Thanks.

sqfmi, 2020-01-09:
Hey @MarquisdeGeek , reach out to us via Tindie with your order number, and we'll ship the adapter boards to your mailing address. Thanks!

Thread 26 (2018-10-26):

What have you built?

pastorhudson, 2018-10-26:
This isn't an issue, but not sure where else to talk about this.

I just finished proof of concept of a Check-in security badge we use at our Church.
https://github.com/pastorhudson/PCOBadge

What have you guys/gals built using Badgy?

lastfuture, 2019-05-20:
I've built a small status monitor for my GitLab issues from work that refreshes hourly. A few coworkers have already told me they'd like something similar.

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

lasniko, 2020-01-10:
I built an actual name badge (I am not very creative).
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
It is a first generation badgy (blue PCB) with a custom 3D printed frame (Nylon filament) and a magnetic clothing attachment glued to the back. It randomly cycles through various teacher certifications every few minutes using the ESP deep sleep (I tried to do a linear slideshow using system_rtc_mem to count and store the index of which logo to display, but failed. So now it just randomly picks one each wake-up)

boettner, 2020-01-31:
Great Ideas!

I‘m working on a train station dashboard. (I‘d like to know how much time is left for drinking coffee before I‘m ready to go.)

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

pastorhudson, 2020-01-31:
@boettner I love that! That's so cool!

bwente, 2020-06-17:
I just made a desktop display last night.

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

I wish on/off switch was a bit more accessible for the case. Can the button be used to do a reset?

https://www.reddit.com/r/esp8266/comments/hawrqr/dad_jokes_for_fathers_day/

chunkysteveo, 2020-06-18:
@bwente  - looks gorgeous! (funny joke too!!) You could re-purpose the main button to be used in the sketch to trigger an ESP_reset. You'd need to check for it being pressed in the loop, and then trigger a function to call the ESP to reset.

chunkysteveo, 2020-06-18:
@bwente  - this example may help you with your wrapping issue:

`char str[] ="Hello World! Here is some text. I need them to split into multiple lines without breaking the words.";
const int wantedLength = 20;

const char * split (const char * s, const int length)
  {
  // if it will fit return whole thing
  if (strlen (s) <= length)
    return s + strlen (s);

  // searching backwards, find the last space
  for (const char * space = &s [length]; space != s; space--)
    if (*space == ' ')
      return space;

  // not found? return a whole line
  return &s [length];
  } // end of split

void setup ()
  {
  Serial.begin (115200);
  Serial.println ();

  const char * p = str;

  // keep going until we run out of text
  while (*p)
    {
    // find the position of the space
    const char * endOfLine = split (p, wantedLength);

    // display up to that
    while (p != endOfLine)
      Serial.println (*p++);

    // finish that line
    Serial.println ();

    // if we hit a space, move on past it
    if (*p == ' ')
      p++;
    }
  }  // end of setup

void loop () { }`

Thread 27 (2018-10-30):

Button Phantom Pressses

pastorhudson, 2018-10-30:
I have a [working sketch](https://github.com/pastorhudson/PCOBadge) that connects to an api and pulls check-in information and displays it on the badge when I press the right toggle button. I'd like to also display the check-in barcode when I press left.

When I started testing this I found that the left button and down button are triggered all the time.
After I click right it immediately triggers left and down. I've increased the milliseconds on the debounce but it had no effect. It didn't change how fast it was triggered either.

Either my button is defective or something else is interfering?

Is anybody else having this issue?

Has anybody solved it?

chunkysteveo, 2018-10-30:
I assume this is related to [issue20](https://github.com/sqfmi/badgy/issues/20) when running on battery (if it is reset and boots) the buttons get triggered randomly. If you run on USB, it should work fine. Running on battery (if you have it working on USB, then unplug) the button presses will appear..... correct?

pastorhudson, 2018-10-30:
I get the button presses when plugged into USB and when unplugged. I set a Serial.println to trigger when a button is presses and it triggers on USB. It also triggers the screen change I setup when It's off USB.

chunkysteveo, 2018-10-30:
You have the white version PCB board? Looks like the USB2Serial chip is interfering.

sqfmi, 2018-10-30:
The serial TX/RX pins GPIO1 & GPIO3 are shared with the direction buttons left & down (refer to the [schematic](https://github.com/sqfmi/badgy/blob/master/hardware/schematic.pdf)). This is why you will receive "phantom" presses when using the serial terminal. The USB-Serial functionality is only meant for uploading sketches.

If your application requires a serial terminal, you can remove the down & left button (GPIO 1 & GPIO 3) from the polling loop. For data input/output applications, we recommend using WiFi (e.g. http/websockets/etc.)

chunkysteveo, 2018-10-30:
Ahhh yes I recall now - the TX/RX pins. @pastorhudson  check your sketch for any "Print Serials" that may be going up/down the pins and falsely triggering a button press.... totally forgot about that @sqfmi , not the USB2Serial issue causing this!

pastorhudson, 2018-10-30:
Ok maybe I left some Serial code in the sketch and that caused it to trigger when it was running on battery. I'll double check my code, test and report back.

pastorhudson, 2018-10-30:
That was the problem! I had missed some Serial commands. Thank you!

pastorhudson, 2018-10-30:
I spoke too soon. I'm using the method of starting it on usb power and then unplugging it to run on battery. (I have the white version)
It was working fine plugged into a USB power source(Wall Wart not computer) and then when I unplugged the usb power it started doing the left down presses again.

chunkysteveo, 2018-10-31:
@pastorhudson - on Battery the CH340C seems to be interfering with the ESP8266 and the button presses. To make the 5-way work they have had to share GPIO ports, and the TX/RX of the CH340C are also the UP and DOWN button press when pulled low. I would advise getting rid of your "case 0,1 and 4" in the button "switch case" in the loop, and remove all serial code lines (just looked at your githhub code).

pastorhudson, 2018-10-31:
@chunkysteveo Thanks for the ideas. This is the code I tested for the comment where I reopened the issue. I didn't push to github because it has some other dev stuff I'm not ready to push yet.

```
/*  PCOBadge is a fun project by Ron Hudson.
    PCOBadge pulls an individual's checkin info from the Planning Center Check-ins api and displays it on an e-paper display.
    It lives at https://github.com/pastorhudson/pcobadge
    It is Liscenced under the:

  MIT License

  Copyright (c) 2018 Ron Hudson

  Permission is hereby granted, free of charge, to any person obtaining a copy
  of this software and associated documentation files (the "Software"), to deal
  in the Software without restriction, including without limitation the rights
  to use, copy, modify, merge, publish, distribute, sublicense, and/or sell
  copies of the Software, and to permit persons to whom the Software is
  furnished to do so, subject to the following conditions:

  The above copyright notice and this permission notice shall be included in all
  copies or substantial portions of the Software.

  THE SOFTWARE IS PROVIDED "AS IS", WITHOUT WARRANTY OF ANY KIND, EXPRESS OR
  IMPLIED, INCLUDING BUT NOT LIMITED TO THE WARRANTIES OF MERCHANTABILITY,
  FITNESS FOR A PARTICULAR PURPOSE AND NONINFRINGEMENT. IN NO EVENT SHALL THE
  AUTHORS OR COPYRIGHT HOLDERS BE LIABLE FOR ANY CLAIM, DAMAGES OR OTHER
  LIABILITY, WHETHER IN AN ACTION OF CONTRACT, TORT OR OTHERWISE, ARISING FROM,
  OUT OF OR IN CONNECTION WITH THE SOFTWARE OR THE USE OR OTHER DEALINGS IN THE
  SOFTWARE.

*/

/* Libraries You Need */

/* e-paper display lib Version 3.x
   https://github.com/ZinggJM/GxEPD/releases */
#include <GxEPD.h>
#include <GxGDEH029A1/GxGDEH029A1.h>
#include <GxIO/GxIO_SPI/GxIO_SPI.h>
#include <GxIO/GxIO.h>

/* include any other fonts you want to use https://github.com/adafruit/Adafruit-GFX-Library */
#include <Fonts/FreeSansBold9pt7b.h>
#include <Fonts/FreeSansBold12pt7b.h>
#include <Fonts/FreeSansBold18pt7b.h>
#include <Fonts/FreeSansBold24pt7b.h>

/* lable.h is a byte encoded version of label.bmp Label Image */
#include "label_cbc.h"
#include "apiStatus.h"
#include "labelMenuBeta.h"

/* WiFi  libs*/
#include <ESP8266WiFi.h>
#include <ESP8266HTTPClient.h>
#include <WiFiClient.h>
#include <DNSServer.h>
#include <ESP8266WebServer.h>
#include <ESP8266HTTPUpdateServer.h>
#include <WiFiManager.h>

/* Misc Libs */
#include <ArduinoJson.h>
#include <Time.h>
#include <TimeLib.h>
#include <base64.h>

/* Always include the update server, or else you won't be able to do OTA updates! */
/**/const int port = 8888;
/**/ESP8266WebServer httpServer(port);
/**/ESP8266HTTPUpdateServer httpUpdater;
/*                                                                                */

/* Configure pins for display */
GxIO_Class io(SPI, SS, 0, 2);
GxEPD_Class display(io); // default selection of D4, D2

/* A single byte is used to store the button states for debouncing */
byte buttonState = 0;
byte lastButtonState = 0;   //the previous reading from the input pin
unsigned long lastDebounceTime = 0;  //the last time the output pin was toggled
unsigned long debounceDelay = 80;    //the debounce time

/* Font Styles */
const GFXfont* h1 = &FreeSansBold24pt7b;
const GFXfont* h2 = &FreeSansBold18pt7b;
const GFXfont* h3 = &FreeSansBold12pt7b;
const GFXfont* h4 = &FreeSansBold9pt7b;

/* EDIT THIS! API Keys And URL's */
String userID = "xxxxxxxx"; // Your User ID Number from check-ins. Use Just the Numerical Portion.

/* Generate your Application ID and Secret personal access token pair at https://api.planningcenteronline.com/personal_access_tokens/new
   Be sure to allow access to Check-ins Version 2018-08-01 */
String applicationID = "xxxxxxxxxx"; // Application ID
String secret = "xxxxxxxxxxx"; // Secret

/* Maybe edit this ¯\_(ツ)_/¯ SHA1 fingerprint of the certificate for api.planningcenteronline.com Expires Nov 24, 2019 */
String fingerPRINT = "95 54 E1 9C 51 F1 9E 0A 2E 2F 41 51 9D A4 E4 83 26 80 71 7C‎";

/* checkinAPIURL is the Check-ins api url using the userID from above.
   b64auth is the Base64 Encoded applicationID:secret
   You shouldn't need to edit these.*/
String apiStatusURL = "http://status.planningcenteronline.com/index.json";
                      String checkinAPIURL = "https://api.planningcenteronline.com/check_ins/v2/people/" + userID + "/check_ins?per_page=1/";
String b64auth = base64::encode(applicationID + ":" + secret, false); // Base64 Encoded auth string

bool OTA = false; //OTA mode disabled by default

void setup()
{
  display.init();

  pinMode(1, INPUT_PULLUP); //down
  pinMode(3, INPUT_PULLUP); //left
  pinMode(5, INPUT_PULLUP); //center
  pinMode(12, INPUT_PULLUP); //right
  pinMode(10, INPUT_PULLUP); //up
  /* WiFi Manager automatically connects using the saved credentials, if that fails it will go into AP mode */
  WiFiManager wifiManager;
  wifiManager.autoConnect("PCOBadge");

  /* If the center button is pressed on boot, enable OTA upload */
  if (digitalRead(5) == 0) {
    httpUpdater.setup(&httpServer);
    httpServer.begin();
    menu();
    /* Otherwsie, Display PCO Badge from Last Check-in */
  } else {
    menu();
  }
}

void loop()
{
  httpServer.handleClient();

  byte reading =  (digitalRead(1)  == 0 ? 0 : (1 << 0)) | //down
                  (digitalRead(3)  == 0 ? 0 : (1 << 1)) | //left
                  (digitalRead(5)  == 0 ? 0 : (1 << 2)) | //center
                  (digitalRead(12) == 0 ? 0 : (1 << 3)) | //right
                  (digitalRead(10) == 0 ? 0 : (1 << 4)); //up

  if (reading != lastButtonState) {
    lastDebounceTime = millis();
  }
  if ((millis() - lastDebounceTime) > debounceDelay) {
    if (reading != buttonState) {
      buttonState = reading;
      for (int i = 0; i < 5; i++) {
        if (bitRead(buttonState, i) == 0) {
          switch (i) {
            case 0:
              //do something when the user presses down
              showText("You pressed the down button!");
              break;
            case 1:
              //do something when the user presses left
              apiSTATUS();
              break;
            case 2:
              //do something when the user presses center
              menu();
              break;
            case 3:
              //do something when the user presses right
              pcoAPI();
              break;
            case 4:
              //do something when the user presses up
              myMSG();
              break;
            default:
              break;
          }
        }
      }
    }
  }
  lastButtonState = reading;
}

/* Gets the last checkin info for userID.  */
void pcoAPI()
{
  display.setRotation(3); //even = portrait, odd = landscape
  display.fillScreen(GxEPD_WHITE); // Clear Screen
  display.drawBitmap(label, 0, 0, 296, 128, GxEPD_WHITE); // Draw the label.h background image
//  display.update();
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
chunkysteveo, 2018-10-31:
That's a lot of code! But all looks fine. My thought i didn't say, Which is what you have already said - was to use the other buttons as a work around. It's a cool script by the way, watched your video!

pastorhudson, 2019-05-29:
Closing this up unless anybody else is experiencing it

Closed 2019-05-29.

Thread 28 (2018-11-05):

@sqfmi Hmm.. Reset didn't work for me - the LED on the ESP8266 blinks when reset - but nothing. In fact, I get absolutely nothing happenng now :( sketches won't upload and the currently loaded sketch (weather) won't refresh :,( Oh, and the circled component is scortching hot -

JonPrevost, 2018-11-05:
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

_Originally posted by @ibuildrockets in https://github.com/sqfmi/badgy/issues/20#issuecomment-430591985_

JonPrevost, 2018-11-05:
Left on with websocketDraw example and I'm having the same problem. This is very hot and nothing is working now. It was left on for 2 days. Will not reset. The CH340C is still in-place, unmodified board.

ibuildrockets, 2018-11-17:
I've tested the hot component. Ambient is 25ºC (77ºF) and the component is at 89ºC (192.5ºF)

Again, no life in the badge :(

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

sqfmi, 2019-01-02:
The inductor shouldn't be that hot ♨️ ! Please try replacing it with an equivalent 68uH 1210 inductor, or reach out to us with your order number and we'll send you a replacement board.

ibuildrockets, 2019-01-06:
Oh that's super! Tindie order number is 122802 under the name Sascha Grant.

ibuildrockets, 2019-01-15:
@sqfmi Thank you for shipping a replacement PCB :) I've not transferred the display across yet. I've just ordered the PCB from OHS Park - What's the difference between CP2104-F03-GMR and CP2104-F03-GM - does it matter? Just wanting to get the IC on the way, too :)  Figure that I'll get that on the board first.

sqfmi, 2019-05-18:
@ibuildrockets they should both be the same, just different packaging. Closing this issue now.

Closed 2019-05-18.

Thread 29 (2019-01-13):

Weather sketch is broken

dh312, 2019-01-13:
Hi, the weather sketch is broken. Forecast request dies with a json parsing error. Not sure where the problem is...tried and failed to figure it out. Best I could tell it looks like stuff is left in the buffer after the first current conditions call. Also setting imperial units does not change the conversions or the displayed units deeper in the code, which makes setting the constant somewhat pointless:
    259 display.print(String((int)(wind*3.6))+"km/h");
    268 display.println(String((int)current_temp) + "C");

JoergSn, 2019-01-26:
Regarding the forecast weather, sometimes the json is too large for the Badgy to handle it. Found a solution:

// use **cnt=25**; might be enough for three days etc.
// it's undocumented, but it works
String url = "/data/2.5/"+type+"?id="+CITY_ID+"&units="+UNITS+"**&cnt=25**&appid="+API_KEY;
// String url = "/data/2.5/"+type+"?id="+CITY_ID+"&units="+UNITS+"&appid="+API_KEY; // we get often to much data for this little thing, cannot handle it

mrWheel, 2019-05-10:
Latest version of arduinoJSON (6.n) does not work with this sketch.
Should be updated!

sqfmi, 2019-05-18:
Weather example has been updated. Closing this issue for now.

Closed 2019-05-18.

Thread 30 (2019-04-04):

Blue PCB not starting on battery, USB is fine

emanuelstanciu, 2019-04-04:
Discussed this on #20 , pasting here the conversation relevant for this new issue:

@sqfmi Hi, I have one of the blue PCB models which was bought in July last year and I suffer from exactly the same behaviour as described on this post. Any idea what's happening?
Works fine on USB power, but on Battery simply flashes the ESP blue LED and the nothing happens.
Any pointers are greatly appreciated - if it helps: Tindie Order #115523

Thanks @chunkysteveo for the quick response

emanuelstanciu, 2019-04-04:
Please let me know if you want me to provide any details to get this progressed, not sure how to move forward with this one

chunkysteveo, 2019-04-04:
Are you able to confirm the voltage of the battery? With a multi-meter?

emanuelstanciu, 2019-04-04:
I am, will do this as soon as I get home tonight. Cheers

emanuelstanciu, 2019-04-05:
3.27V - brand new battery
I can offer something that might bring some light to this story; I am using a CR battery (non-rechargeable), not a LIR that I've seen around various articles. Can this be an issue, in terms of Amperage?
I tried 3 batteries already, same effect

chunkysteveo, 2019-04-05:
You HAVE to use a LIR if you plug it into USB for power, as the board has a charging circuit and WILL try to charge it. The voltage is fine though, not the issue.

So when you have it plugged into USB, how do you know it works? When on battery and you flick the switch to on - how do you know it's not working?

emanuelstanciu, 2019-04-05:
I ordered a LIR and will test it over the weekend. But it should still work on battery, does a CR provide the right amount of current?
on USB, ESP flashes blue and then a few seconds later the sketch is loaded (hello.h) and I see the screen updating. I can also put it in OTA mode and can access the URL from my laptop
on battery, there's the same brief flash of the bllue LED on ESP and then absolutely nothing happens/works
I can do a quick video if you want to see it, let me know and thanks for your help with it

chunkysteveo, 2019-04-05:
The current will be fine between a normal CR3032 and an LIR3032, no issue.

That is odd behaviour. When you switch it on when on battery - it would be worth you checking your WiFi networks on your phone/PC - can you see a Badgy access point? Or an ESP access point? I recall something similar to me where I wasn't totally sure it was working or not, but it turned out I needed to connect to it via phone, enter my WiFi credentials of my home WiFi, and then it worked fine.... Worth a go?

Steve

sqfmi, 2019-04-06:
Hi @emanuelstanciu,

You **MUST** use the LIR2450 battery as stated on the Tindie product page.

CR batteries (non-rechargeable button cell type) have a nominal voltage of 3V, and will not sufficiently power badgy, as the ESP8266 requires 3.3V. In addition, the LDO regulator expects a higher voltage so it can step down to 3.3V.

LIR batteries (rechargeable button cell type) have a nominal voltage of 3.6V; this gets stepped down by the LDO to 3.3V.

The blue LED flash you see is the ESP8266 trying to boot up on insufficient voltage input.

Thanks @chunkysteveo for chiming in to support :)

chunkysteveo, 2019-04-06:
Ahhh...i didn't know there was such a difference in the CR and LiR?! And apologises- i said the 2032, but it's the bigger 2450 versions.

emanuelstanciu, 2019-04-06:
Thank you both. The LIR2450 arrived today and indeed it worked without an issue. Tanks again for a great product.

Closed 2019-04-06.

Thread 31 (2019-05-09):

Screen Alignment Issue - Rev 2B

bmlzootown, 2019-05-09:
Got the new Rev 2B board the other day, but I was sick so I didn't get to tinker right away. Pulled it out earlier today and, upon uploading the hello example (slightly modified with my initials instead), I realized that the screen was misaligned. Even the ["Badgy AP" screen](https://i.imgur.com/f3yGCKx.jpg) seems to be misaligned.

I'm new to... well, all of this, so I apologize if my description isn't quite apt. Is there a simple solution that I'm just completely unaware of?

Thanks!

sqfmi, 2019-05-10:
Could you check to make sure the screen's ribbon cable is properly attached to the connector? This happens sometimes when it's loose or misaligned.

bmlzootown, 2019-05-10:
No luck -- the [end result](https://i.imgur.com/uvBQaki.jpg) still appears to be the same, even when [completely removed and then reconnected](https://i.imgur.com/Gq2NkEI.jpg).

sqfmi, 2019-05-10:
The connection looks good. The display appears to be not refreshing the whole screen, but just the misaligned section. The only time we've encountered this is when the ribbon cable is not aligned or loose... can you provide more details on your setup so we could try to help troubleshoot?

mrWheel, 2019-05-10:
Help!
I'm having the same issue!
How do I remove/re-insert the ribbon cable without breaking my Badgy?
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

sqfmi, 2019-05-10:
Could you also try power cycling a few times, and using a different USB cable/port?

mrWheel, 2019-05-10:
This is what I did:
- replaced the battery
- changed USB cable
- switched on/off with USB cable attached
- switched on/off without USB cable with old and with new battery

No change :-(

sqfmi, 2019-05-10:
@mrWheel what type of battery is being used?

mrWheel, 2019-05-10:
LIR2450’s

sqfmi, 2019-05-11:
One more thing to try, could you remove all power sources (i.e. battery and USB) and wait a few seconds, then with the switch already in the **ON** position, plug in the USB cable?

This is weird behavior and new to us, we have not been able to deterministically reproduce the same misaligned results. We will continue to investigate this issue.

bmlzootown, 2019-05-11:
Did the above: removed all power sources, flipped the switch to the ON position, and then plugged in the usb cable. The entire screen updated this time.
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

Turning the switch back OFF before re-plugging the cable reproduces the partial screen update issue.
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

Interestingly enough, after doing the above (returning to a partial screen update), it then took me a good 3-4 more tries to get the full screen to update again using the process described in your last reply/

mrWheel, 2019-05-11:
Ok, did that.
-Battery removed
- USB disconnected
- switch on .. off .. on .. off .. on
> nothing happens on the screen though
Result is the same mis-alignment

peteargles, 2019-05-18:
Figured I should log in and chime in.
Mine arrived last week and I had the same screen alignment issue.
I removed and reinserted the ribbon cable and it's been perfect ever since.

Lupuseli, 2019-05-28:
I have experienced the same issue. However, it manifests depending on the power supply: whenever I have used a power supply/charger which had Qualcomm’s Quick Charge or Samsung’s Adaptive Fast Charging (both exceed the USB spec’s voltage parameters) I noticed the screen alignment issue. The solution was using a different power supply (standard USB-PD, like the ones used to power Raspberry Pi's). Goes back to normal after one power cycle.

Jonzay, 2019-05-31:
I also experienced the same issue while I was uploading code via USB from my PC, with the LIR2450 battery connected. It went away when I removed the battery. I've only just reinserted the battery (tested fine running the code I had uploaded), so I will see if I can get the issue to reoccur tonight and create specific steps for replicating the issue.

clsn, 2019-06-02:
I'm having the same problem, and I don't even have any battery installed yet.  I'll try disconnecting from power with the switch ON, in the hopes that it'll reset everything as it seems to have for those above.

afonso360, 2019-06-15:
Had the same issue, it comes and goes, when i unboxed it, it didn't update the full screen, a few hours later it updated the entire screen. Today, partial update again, removed and reinserted the ribbon cable, and its ok now.

noxo, 2019-06-21:
I have the same issue, have been powering the device via USB only (laptop USB-port). Not sure, but it seems that removing the power source (USB-cable) for 30 secs or so, and then reconnecting the power source seemed to fix the thing.

Jonzay, 2019-06-28:
> I will see if I can get the issue to reoccur tonight and create specific steps for replicating the issue.

Well, it's finally tonight :P

I got the Badgy out to upload new code (to try to get it onto WPA2-Enterprise networks), had it switched off but with the LIR2450 battery in it, plugged in the cord, switched the switch on and experienced the issue. I could only get full screen updates back again by removing the USB, switching the switch off, removing the battery, switching the switch on and then plugging in the USB cable. It is behaving itself again.... for now.

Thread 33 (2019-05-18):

Badgy does not reset after flashing via USB

lastfuture, 2019-05-18:
Hello,

my Badgy Rev 2B does not reset itself after successfully flashing it via the Arduino IDE through USB. The upload log reads "Hard resetting via RTS pin..." but the display will remain in the state it was in during upload unless I either toggle the on/off switch or I powercycle the badge by unplugging and plugging the USB cable.

The behavior is the same with all example sketches as well as my own test sketches down to the very basics of simply displaying a text without any Wifi capability.

"Reset Method" is set to "ck", but neither of the other available options changes the behavior.

What do I have to do to make Badgy reset itself upon successful upload via the Arduino IDE?

sqfmi, 2019-05-18:
Hi @lastfuture ,

Badgy uses the [two transistor circuit](https://tttapa.github.io/Images/thumbs/auto-reset_auto-program.png) for autoreset using the DTR/RTS lines. You can select '**nodemcu**' for 'Reset Method' and it should perform the reset after upload.

If that is not working either, you can check the [green PCB](https://raw.githubusercontent.com/sqfmi/badgy/master/website/img/badgy_fix_2.JPG) in the back to see if there are any issues with the DTR/RTS connection spots.

The power switch also serves as reset, but ideally it should work through the autoreset mechanism.

Xaldimo, 2019-05-18:
I have noticed with version 2.5.0+ version of the ESP8266 board driver the reset doesn't work any more. Either using the ESP8266 Boards or NodeMCU 1.0 (ESP-12E Moldule)

lastfuture, 2019-05-19:
I couldn't make a difference using the software options alone and after setting the board to NodeMCU 1.0 the reset option disappeared altogether. Neither with the "Reset Method" set to nodemcu nor with the board set to NodeMCU 1.0 does Badgy reset after an upload.

The soldering on the connection spots looks fine. I have no oscilloscope but I was able to check for continuity and the tops of the DTR/RTS pads connect to the top and bottom 10k resistors respectively that are directly right of the green PCB (as parts of the two transistor circuit you mentioned I assume).

lastfuture, 2019-05-19:
I can confirm that after downgrading from version 2.5.1 to version 2.4.2 I'm now seeing autoreset working as expected. I had to change my sketch though because I was using SSL certificate fingerprints which 2.4.2's WiFiClientSecure doesn't seem to support yet.

sqfmi, 2019-05-22:
Closing as this issue relates to the ESP8266 Arduino library, adding a note to the troubleshooting guide.

Closed 2019-05-22.

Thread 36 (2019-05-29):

Failed to connect to ESP8266: Invalid head of packet (0x62)

AlanCunningham, 2019-05-29:
I was having a go at putting micropython on the board, however mistakenly attempted to upload the "esp8266-20190125-v1.10.bin" micropython file via the OTA method rather than USB.

I'm now trying to install the default badgy.bin file via Arduino to start again however get the following exception:

```
Sketch uses 333532 bytes (31%) of program storage space. Maximum is 1044464 bytes.
Global variables use 37136 bytes (45%) of dynamic memory, leaving 44784 bytes for local variables. Maximum is 81920 bytes.
esptool.py v2.6
2.6
esptool.py v2.6
Serial port COM4
Connecting........_____....._____....._____....._____....._____....._____.....____Traceback (most recent call last):
  File "C:\...\Arduino15\packages\esp8266\hardware\esp8266\2.5.2/tools/upload.py", line 25, in <module>
    esptool.main(fakeargs)
  File "C:/.../Arduino15/packages/esp8266/hardware/esp8266/2.5.2/tools/esptool\esptool.py", line 2653, in main
    esp.connect(args.before)
  File "C:/.../Arduino15/packages/esp8266/hardware/esp8266/2.5.2/tools/esptool\esptool.py", line 468, in connect
    raise FatalError('Failed to connect to %s: %s' % (self.CHIP_NAME, last_error))
esptool.FatalError: Failed to connect to ESP8266: Invalid head of packet (0x6C)
esptool.FatalError: Failed to connect to ESP8266: Invalid head of packet (0x6C)
```

Would this be due to uploading the micropython .bin file via OTA?  Can I reset Badgy or still put micropython on it?

sqfmi, 2019-05-29:
Try using the esptool and erasing the flash. You may also have to toggle the on/off switch at the right time if you are unable to get it into upload mode.

cunnia06, 2019-05-29:
Thanks for the reply.  Regarding toggling the on/off switch at the right time to force into upload mode - is there a specific time to do this?  E.g. a few seconds after plugging the USB in?

AlanCunningham, 2019-05-29:
Thanks for the reply.  Regarding toggling the on/off switch at the right time to force into upload mode - is there a specific time to do this?  E.g. a few seconds after plugging in the USB?

chunkysteveo, 2019-05-29:
It all depends on the sketch. The on/off switch won't put it into upload mode - but most of the badgy sketched use the deepsleep, so once it's booted and done "whatever task" it will shut down. I found a little more reliable is to hold the joystick button down on boot. This (usually - again, depends on the sketch) will put it into OTA Upload mode and not set it to go to sleep. It will be sat waiting for a HTTP upload, but more importantly will be up and running and able to accept Tx Rx signals from the USB chip.

AlanCunningham, 2019-05-29:
Success!  Using esptool to erase the flash did the job.  In case anyone finds themselves in the same situation as me, here's the steps I took to erase the flash and put micropython on the board:

- Plug the board in with the On/Off switched to Off
- Run `$ esptool.py --port /dev/tty.SLAB_USBtoUART erase_flash` (Your port may vary)
- You'll see a `Connecting........_____` message
- During this message, hold down the joystick button and turn the switch to On.  Then release the joystick button.  Doing this near the beginning of the "Connecting" message worked for me.

Full output:
```
$ esptool.py --port /dev/tty.SLAB_USBtoUART erase_flash
esptool.py v2.6
Serial port /dev/tty.SLAB_USBtoUART
Connecting........_
Detecting chip type... ESP8266
Chip is ESP8266EX
Features: WiFi
MAC: 84:f3:eb:84:63:66
Uploading stub...
Running stub...
Stub running...
Erasing flash (this may take a while)...
Chip erase completed successfully in 7.1s
Hard resetting via RTS pin...
```

Installing micropython was then a similar process:
```
$ esptool.py --port /dev/tty.SLAB_USBtoUART --baud 460800 write_flash --flash_size=detect 0 esp8266-20190529-v1.11.bin
esptool.py v2.6
Serial port /dev/tty.SLAB_USBtoUART
Connecting........_____....._
Detecting chip type... ESP8266
Chip is ESP8266EX
Features: WiFi
MAC: 84:f3:eb:84:63:66
Uploading stub...
Running stub...
Stub running...
Changing baud rate to 460800
Changed.
Configuring flash size...
Auto-detected Flash size: 4MB
Flash params set to 0x0040
Compressed 617880 bytes to 402086...
Wrote 617880 bytes (402086 compressed) at 0x00000000 in 9.6 seconds (effective 517.5 kbit/s)...
Hash of data verified.

Leaving...
Hard resetting via RTS pin...
```

Badgy now broadcasts the Micropython AP successfully.  Thanks very much for your help!

chunkysteveo, 2019-05-29:
Awesome, glad the little joystick hack worked for you!

Closed 2019-05-29.

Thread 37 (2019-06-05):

Can Badgy measure the voltage of the battery?

mrWheel, 2019-06-05:
Is it possible (with minor modifications, if needed) to measure the voltage of the battery?

chunkysteveo, 2019-06-05:
You can - jumper the ADC pads on the back and that will give you the voltage as an analogue readout using the built in ADC of the ESP8266 chip.

sqfmi, 2019-11-18:
Moved to Wiki https://github.com/sqfmi/badgy/wiki/Can-Badgy-measure-the-voltage-of-the-battery%3F

chunkysteveo, 2022-09-26:
Adding to this all the way in 2022(!) Bridging the ADC solder jumper will only measure up to 3.3V as the voltage divider is 220k/100k - to get a more accurate battery voltage you should bridge the ADC jumper with a 100k resistor, which will bring the recorded ADC value closer to 4.2V when at or near 1V seen on the ADC ( voltage divider will be  = 320k / 100k).

Closed 2019-11-18.

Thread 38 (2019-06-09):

What is the meaning of the blue LED (not the one on the ESP8266)

mrWheel, 2019-06-09:
Hi,

When I apply USB power to the Badgy a blue LED lights up (not the LED on the ESP8266). I have seen before that after a while the blue LED blinks but recently is only fades and it seems the battery is not charged ...

What is the LED  supposed to do?
What is the information it gives when on, off, blinking, and faded?

chunkysteveo, 2019-06-10:
The LED is part of the TP4054 charge circuit, and is attached to the CHRG (or STAT) pin of the TP4054 chip from Vusb and a 2K resistor. That pin has a tri-state, low, high, and high impedance. It's a tricky pin and tricky state to understand, even I don't fully "get it". But the best write up I can find from the spec sheets is this:

CHRG is the open-drain status indication output. When the charger is in the charging state, CHRG is pulled down to low level. After the charging is completed, the CHRG pin is in the high-impedance state; if the battery is not connected, the BAT pin voltage is inserted when the charger is inserted. At about 4.6V, the indicator will flash indicating a missing battery or bad battery contact.

When the charger charges the battery, the CHRG pin is pulled low by the internal switch to indicate that the charging is in progress; when charging is completed, the CHRG pin is in a high-impedance state and the indicator light flashes when the battery is inserted and the battery is disconnected, missed battery or bad battery contact.

So to answer your setup - a flashing LED would indicate that there is no battery present when plugged into USB power. If your battery is not charging, there may be an issue with the TP4054 chip, or the battery.  I have a similar issue with an old version of the badgy - replaced the TP4054 and still won't charge. I need to start looking at the circuit paths in more details to see where it may have failed.

Hope that helps.

sqfmi, 2019-11-18:
Moved to Wiki https://github.com/sqfmi/badgy/wiki/What-is-the-meaning-of-the-blue-LED-(not-the-one-on-the-ESP8266)

Closed 2019-11-18.

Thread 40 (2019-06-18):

Unable to wake from DeepSleep

liorbp, 2019-06-18:
Hi there,

I just realized I did something stupid by calling some function directly from setup() that ends with the sequence below and now I'm unable to flash a new sketch
```
delay(1000);
ESP.deepSleep(1 - 1000000UL);
```

I noticed this in the README:
> Note that if the ESP chip is in a deep sleep then it will not automatically respond to the upload request and you may see something like "error: espcomm open failed" when trying to upload. A manual restart of the ESP chip, using the power slide button, just prior to upload gives you a small window of time to upload.

I was trying everything, switching the button, run the flash command using esptool in a loop and connecting the badgy while it runs. Nothing I did allowed me to re-flash it.
My attempts will always end with:
```
warning: espcomm_sync failed
error: espcomm_open failed
error: espcomm_upload_mem failed
```

I suspect that at some point the esptool failed to flash the firmware to the ESP-12F chip and it causes the fail at boot.
Any chance [this ](https://robertoostenveld.nl/esp-12-bootloader-modes/) would help?

chunkysteveo, 2019-06-18:
Have you kept the OTA Sketch upload part from the example sketches? This is where you hold down the centre button of the joystick to get it into upload mode from a web interface. If you do that, it will keep the ESP8266 alive while it waits you to upload a BIN file. Ignore that, but now the ESP8266 is no longer running the sketch so will be able to be flashed. Can you post your whole code to this to see at what point you have added the sleep part?

liorbp, 2019-06-18:
Unfortunately, I didn't keep the OTA Sketch upload section (as I said, stupid).
The sketch was something like the below code... is it game over to my badgy? :(

```
GxIO_Class io(SPI, SS, 0, 2);
GxEPD_Class display(io);

void setup()
{
  Serial.begin(115200);
  display.init();
  myfunc();
}

void loop()
{
}

void myfunc()
{
  delay(1000);
  ESP.deepSleep(1 - 1000000UL);
}
```

chunkysteveo, 2019-06-19:
No, it's not game over... you have a delay in there of a second, and the boot up from sleep also takes some time. The quick way will just be a case of trying to upload your sketch to the board, and timing the off/on right so it (the USB 2 Serial chip) catches the ESP8266 in it's boot up and sketch loading state. What revision board do you have?

A longer and harder way would be to manually upload some code to the ESP8266 using some Dupoint cables and connecting up power, ground, RT, TX and setting the GPIO appropriatley. But you would need an external serial programmer, even a spare Wemos D1 mini or Node MCU would do. As you have spotted in your link, the pins would need to be:

UART Download Mode (Programming): GPIO 0 -  LOW, GPIO 2 - HIGH, GPIO 15 LOW.

This will force the chip into programming mode when you power it up and you are not relying on the Badgy USB2Serial chip catching it in time. Then you can upload at your leisure.

Steve

chunkysteveo, 2019-06-24:
sorted??

Closed 2019-06-24.

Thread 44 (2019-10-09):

problem(s) with new Badgy

jdhysell, 2019-10-09:
I just received the new 2B model and started setting it up.
The first thing I see is that it has a bad solder joint on the mini-USB connector. I have to hold it at an angle to force it to connect to the circuit board... - very unpleasant for long sessions...
I was able to set it up to my local WIFI environment and proceeded to play with the examples.
I modified 'hello' to use my name, and verified and compiled it without issue.
But when I load it to the Badgy, with either WIFI or USB, it completes and informs me that Badgy is restarting. But nothing happens after that - the ink display remains with the connected for update image. Power cycling does nothing (other than letting me restart the OTA process if I want). I tried reloading the base version of 'hello' with the same end results.
Any suggestions?

sqfmi, 2019-10-15:
Hi @jdhysell , may we know the board settings used to compile the sketch?

jdhysell, 2019-10-15:
HiI read through the blog and found this setting page and followed it.
I wiped my initial Arduino 1.8.5 environment and restarted with 1.8.10
no change in how the badgy behaves.
The sketches all compile and behave like they transfer.A message appears that the unit will now reboot, and the wifi signalgoes away briefly. Then wifi returns *so it appears the badgy DOES reboot*but the e-paper never updates from the wifi update screen.
thanks for your supportJohn

    On Tuesday, October 15, 2019, 01:50:28 PM EDT, SQFMI <notifications@github.com> wrote:

Hi @jdhysell , may we know the board settings used to compile the sketch?

—
You are receiving this because you were mentioned.
Reply to this email directly, view it on GitHub, or unsubscribe.

jdhysell, 2019-10-15:
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

chunkysteveo, 2019-10-15:
Change Flash Size to 4M 1M SPIFFS, and try the upload again.

jdhysell, 2019-10-15:
sorryThe prior settings list was wrong
Flash is already set to 4M 1M SPIFFS
I am having trouble getting a snapshot/copy of the tools pulldown page...-John
    On Tuesday, October 15, 2019, 04:17:25 PM EDT, Stephen Ludgate <notifications@github.com> wrote:

Change Flash Size to 4M 1M SPIFFS, and try the upload again.

—
You are receiving this because you were mentioned.
Reply to this email directly, view it on GitHub, or unsubscribe.

jdhysell, 2019-10-15:
On Tuesday, October 15, 2019, 04:17:25 PM EDT, Stephen Ludgate <notifications@github.com> wrote:

Change Flash Size to 4M 1M SPIFFS, and try the upload again.

—
You are receiving this because you were mentioned.
Reply to this email directly, view it on GitHub, or unsubscribe.

jdhysell, 2019-10-15:
Is there any sensitivity to the version of the Adafruit GFX library used?I loaded 1.5.7
I know that version 2.x of  GxEPD is needed 
    On Tuesday, October 15, 2019, 04:17:25 PM EDT, Stephen Ludgate <notifications@github.com> wrote:

Change Flash Size to 4M 1M SPIFFS, and try the upload again.

—
You are receiving this because you were mentioned.
Reply to this email directly, view it on GitHub, or unsubscribe.

sqfmi, 2019-10-15:
Hi @jdhysell, if it compiles and uploads then the version you have should be ok. Could you also check a few things:

1) Confirm you have Rev 2B and not Rev 2C
2) The ribbon cable is properly secured and not loose
3) Power cycling with the on/off button has any effect?

Thanks!

jdhysell, 2019-10-16:
It matches the 2B model on the Github home pageBut then I read the description of the 2C and it DOES appear to havea closed solder pad set marked * on the lower right corner.The protective film did have a green tabSo I am now thinking it is a 2CDo I need a special library for that?
I have reseated the e-paper ribbon cable several times - no joy there
Power switch does not impact the e-paper image at all.The only impact I can observe is the wifi signal dies with power in OFF position*as it should*
thanksJohn Hysell
    On Tuesday, October 15, 2019, 07:41:26 PM EDT, SQFMI <notifications@github.com> wrote:

Hi @jdhysell, if it compiles and uploads then the version you have should be ok. Could you also check a few things:

   - Confirm you have Rev 2B and not Rev 2C
   - The ribbon cable is properly secured and not loose
   - Power cycling with the on/off button has any effect?

Thanks!

—
You are receiving this because you were mentioned.
Reply to this email directly, view it on GitHub, or unsubscribe.

chunkysteveo, 2019-10-16:
Can you connect to the Badgy via it's IP Address?

When you power it up - is it creating a "Badgy" Wifi access point, or is it connecting to your home Wifi network (and you can ping it's IP address and connect to it via e.g. http://192.168.1.XXX:8888/update)?

Steve

jdhysell, 2019-10-16:
YesThat is how I have been uploading to it sincethe micro-USB connection has a bad solder joint.The upload code appears to work fine. After uploads, a messageindicates the unit will reboot. The IP address drops briefly *cannot ping it any more*.The IP address returns - but the e-paper does not change - sits on the code update screen.
thanks
    On Wednesday, October 16, 2019, 07:21:14 AM EDT, Stephen Ludgate <notifications@github.com> wrote:

Can you connect to the Badgy via it's IP Address?

When you power it up - is it creating a "Badgy" Wifi access point, or is it connecting to your home Wifi network (and you can ping it's IP address and connect to it via e.g. http://192.168.1.XXX:8888/update)?

Steve

—
You are receiving this because you were mentioned.
Reply to this email directly, view it on GitHub, or unsubscribe.

jdhysell, 2019-10-16:
OKI made those changes, recompiled, saved new bin and uploaded to the BadgyNo difference observed.The code uploaded and Badgy rebootedBut the e-paper remains on the /update page - power cycling does nothing.
In my copy of hello, the GDEH029A1 driver is referenced in line 3so it is still included after commenting line 4...
thxJohn
    On Wednesday, October 16, 2019, 10:08:49 AM EDT, SQFMI <notifications@github.com> wrote:

@jdhysell with the closed solder * pad tab and a green tab, you should have Rev 2C and not 2B. With Rev 2C, you have to make sure you modify your code to use the GDEW029T5 driver instead of the GDEH029A1. You can do that by uncommenting line 4 and commenting out line 6 in hello.ino

—
You are receiving this because you were mentioned.
Reply to this email directly, view it on GitHub, or unsubscribe.

jdhysell, 2019-10-16:
I see that the example code was updated on 9/28I refreshed my copies and now can compile HELLO just fine
So the solution *for me* was to observe that the code has been updated, andthat I have a version 2C board.
thanks very much for your support.You can close this case.
regardsJohn Hysell
    On Wednesday, October 16, 2019, 10:08:49 AM EDT, SQFMI <notifications@github.com> wrote:

@jdhysell with the closed solder * pad tab and a green tab, you should have Rev 2C and not 2B. With Rev 2C, you have to make sure you modify your code to use the GDEW029T5 driver instead of the GDEH029A1. You can do that by uncommenting line 4 and commenting out line 6 in hello.ino

—
You are receiving this because you were mentioned.
Reply to this email directly, view it on GitHub, or unsubscribe.

chunkysteveo, 2019-10-16:
//Use the GxGDEW029T5 class if you have Badgy Rev 2C. Make sure you are on GxEPD 3.05 or above

Are you using version 3 of the GxEPD? Your previous notes said you installed the V2 version...?

Steve

sqfmi, 2019-10-16:
Thanks @chunkysteveo for your support 👍 Glad to hear it's all working now @jdhysell

dnhuan, 2019-10-17:
sorry for the irrelevant question, did you order your rev2C on Tindie? Or if I buy Badgy on Tindie right now, will I get rev2C, or just 2B?

sqfmi, 2019-10-17:
@dnhuan if you ordered recently, it should be Rev 2C

jdhysell, 2019-10-17:
I received a 2C - I did not realize that until I was toldto examine the board more closely
    On Wednesday, October 16, 2019, 09:21:48 PM EDT, Đoàn Ngọc Huân <notifications@github.com> wrote:

sorry for the irrelevant question, did you order your rev2C on Tindie? Or if I buy Badgy on Tindie right now, will I get rev2C, or just 2B?

—
You are receiving this because you were mentioned.
Reply to this email directly, view it on GitHub, or unsubscribe.

sqfmi, 2019-11-18:
Resolved.

Closed 2019-11-18.

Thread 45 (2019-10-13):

Badgy no longer booting

bauerj, 2019-10-13:
Hey,

I just received my Badgy Rev 2C a few days ago. I tried to modify the "Hello" sketch but had issues uploading it onto the device. The connection was somewhat unreliable so I had to restart the process a few times until it worked. I noticed that the Badgy sometimes rapidly restarted itself (the display turned white and then the content appeared again) while the Arduino IDE tried to start flashing.

However after one failed attempt to flash a new program it seems like the Badgy is no longer booting at all. The screen doesn't change any more and I am unable to get into the web flash mode, which is still part of the sketch.

When turning the device on I see this:

```
ets Jan  8 2013,rst cause:2, boot mode:(3,7)

ets_main.c
```

in the serial monitor. No further output occurs.

Flashing a new sketch seems impossible, as the process stops with `esptool.FatalError: Failed to connect to ESP8266: Timed out waiting for packet header`.

I also tried using a different cable and a different computer but that did not solve the issue. Any idea what could be wrong here?

sqfmi, 2019-10-15:
Hi @bauerj , are you able to see the serial port show up in the Arduino IDE?

bauerj, 2019-10-15:
Yes, and when booting up the device I see the output posted earlier in the serial monitor.

sqfmi, 2019-10-15:
It appears to be crashing and stuck in a restart loop, and you are unable to upload a new sketch. Can you confirm if you are using a stable power source? Also, could you check and see if there are any loose connections or components (a picture of the back of Badgy would be really helpful if possible).

Thanks!

bauerj, 2019-10-17:
Not sure, how to check that. I used a different computer and the issue stayed the same. Measuring the voltage at the ESP-12F shows a stable 3.3V:

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

At the USB port I measure 5.03V but the pins are too tiny to take a photo while measuring.

Here is what the board looks like:

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

I can't see any loose connections with my naked eye.

bauerj, 2019-11-14:
Any idea how I could repair this?

sqfmi, 2019-11-14:
Hi @bauerj , try using the esptool to completely erase the flash and re-uploading the sketch, and make sure you are using the right compile settings. If all else fails, reach out to us on Tindie and we'll send you a new board.

liorbp, 2021-04-25:
@bauerj You could just pull down RST to low (means connecting a cable between RST and ground) and flash it again. It should work.
When you flash it make sure to do it with the _hello_ example (and don't forget to use the right GxEPD before doing so).

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

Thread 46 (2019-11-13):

Not connecting via USB

laird, 2019-11-13:
I am unable to connect to Badgy on a MacBook Pro via USB. I was able to connect and program it with the Hello sketch from the repo via WiFi, once, after which it doesn't respond to WiFi, either. So I need USB programming to recover from that. I've tried several ports and several cables and installed some additional drivers suggested in various forums, but so far it's not recognized as a serial device on USB. Any suggestions?

sqfmi, 2019-11-14:
Hi @laird, do you have the drivers installed? You can find them here https://www.silabs.com/products/development-tools/software/usb-to-uart-bridge-vcp-drivers

Once installted, you should be able to see the device show up in the Arduino IDE e.g. /dev/cu.SLAB_USBtoUART

laird, 2019-11-15:
That did the trick. Thanks!

BTW, I didn’t see these drivers referenced in https://github.com/sqfmi/badgy <https://github.com/sqfmi/badgy> - you should add it. Or is there somewhere else that I should be looking for doc’s?

I’ve got sketches compiling, loading and running now, thanks!

I just noticed that the batteries I bought (Energizer 2450 Lithium battery) don’t seen ti be charging or powering Badgy. I am putting them in + up, which looks right. I did notice that the contact on the PCB (-) doesn’t stick up at all. Perhaps it’s not making contact?

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

sqfmi, 2019-11-15:
Awesome! We'll update this information in the README shortly.

Closed 2019-11-15.

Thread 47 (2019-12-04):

Compiler errors

mattpackwood, 2019-12-04:
I am getting errors and failure to compile, any suggestions?

Arduino: 1.8.10 (Mac OS X), Board: "Generic ESP8266 Module, 80 MHz, Flash, Legacy (new can return nullptr), All SSL ciphers (most compatible), dtr (aka nodemcu), 26 MHz, 40MHz, DOUT (compatible), 1MB (FS:64KB OTA:~470KB), 2, nonos-sdk 2.2.1+100 (190703), v2 Lower Memory, Disabled, None, Only Sketch, 115200"

Multiple libraries were found for "DNSServer.h"
 Used: /Users/mattpackwood/Library/Arduino15/packages/esp8266/hardware/esp8266/2.6.2/libraries/DNSServer
Multiple libraries were found for "ESP8266WebServer.h"
 Used: /Users/mattpackwood/Library/Arduino15/packages/esp8266/hardware/esp8266/2.6.2/libraries/ESP8266WebServer
Multiple libraries were found for "ESP8266HTTPUpdateServer.h"
 Used: /Users/mattpackwood/Library/Arduino15/packages/esp8266/hardware/esp8266/2.6.2/libraries/ESP8266HTTPUpdateServer
Multiple libraries were found for "WiFiManager.h"
 Used: /Users/mattpackwood/Documents/Arduino/libraries/WiFiManager
Multiple libraries were found for "GxEPD.h"
 Used: /Users/mattpackwood/Documents/Arduino/libraries/GxEPD
Multiple libraries were found for "SPI.h"
 Used: /Users/mattpackwood/Library/Arduino15/packages/esp8266/hardware/esp8266/2.6.2/libraries/SPI
Multiple libraries were found for "Adafruit_GFX.h"
 Used: /Users/mattpackwood/Documents/Arduino/libraries/Adafruit_GFX_Library
Multiple libraries were found for "ESP8266WiFi.h"
 Used: /Users/mattpackwood/Library/Arduino15/packages/esp8266/hardware/esp8266/2.6.2/libraries/ESP8266WiFi
fork/exec /Users/mattpackwood/Library/Arduino15/packages/esp8266/tools/python3/3.7.2-post1/python3: no such file or directory
Error compiling for board Generic ESP8266 Module.

This report would have more information with
"Show verbose output during compilation"
option enabled in File -> Preferences.

JonPrevost, 2019-12-17:
I think the board should be NodeMCU 1.0 (ESP-12E Module), not Generic ESP8266 Module. I'm not sure though. I'm revisiting these boards and getting my own headaches compiling.

chunkysteveo, 2019-12-18:
Correct @JonPrevost [point 5](https://github.com/sqfmi/badgy#over-usb-for-rev-2a--rev-2b) states it needs to be NodeMCU 1.0 (ESP-12E Module) if compiling from Arduino IDE. Hope that helps @mattpackwood ?

mattpackwood, 2019-12-18:
That does not seem to help, sorry...

Multiple libraries were found for "WiFiManager.h"
 Used: /Users/mattpackwood/Documents/Arduino/libraries/WhareHauoraWiFiManager
Multiple libraries were found for "GxEPD.h"
 Used: /Users/mattpackwood/Documents/Arduino/libraries/GxEPD
Multiple libraries were found for "SPI.h"
 Used: /Users/mattpackwood/Library/Arduino15/packages/esp8266/hardware/esp8266/2.6.3/libraries/SPI
Multiple libraries were found for "Adafruit_GFX.h"
 Used: /Users/mattpackwood/Documents/Arduino/libraries/Adafruit_GFX_Library
Multiple libraries were found for "ESP8266WiFi.h"
 Used: /Users/mattpackwood/Library/Arduino15/packages/esp8266/hardware/esp8266/2.6.3/libraries/ESP8266WiFi
Multiple libraries were found for "DNSServer.h"
 Used: /Users/mattpackwood/Library/Arduino15/packages/esp8266/hardware/esp8266/2.6.3/libraries/DNSServer
Multiple libraries were found for "ESP8266WebServer.h"
 Used: /Users/mattpackwood/Library/Arduino15/packages/esp8266/hardware/esp8266/2.6.3/libraries/ESP8266WebServer
Multiple libraries were found for "ESP8266HTTPUpdateServer.h"
 Used: /Users/mattpackwood/Library/Arduino15/packages/esp8266/hardware/esp8266/2.6.3/libraries/ESP8266HTTPUpdateServer
fork/exec /Users/mattpackwood/Library/Arduino15/packages/esp8266/tools/python3/3.7.2-post1/python3: no such file or directory
Error compiling for board NodeMCU 1.0 (ESP-12E Module).

mattpackwood, 2020-01-01:
It looks like the badgy is going to recycling...  Oh well...

chunkysteveo, 2020-01-01:
There's no issue with the Badgy board. Those errors are errors in your Arduino IDE compiling your files. I would go back to basics and make sure you can compile and upload a basic blink sketch to the board,  and then some ESP8266 example sketches. It's a great little board and worth getting working. Help @sqfmi ?

Steve

JonPrevost, 2020-01-01:
I'm sure your troubles are in the IDE. I had to muck around with different versions of libraries to get even the example codes to compile. Still not entirely sure of the multiple libraries warnings. I can uninstall and it's still there warning me of multiple versions of spi.h etc.. I noticed that Json wasn't rolling back to an older version so that was a bug I ran into. Good luck with the IDE help, I dont even know how I got it working. The board works really well but it looks less than professional. When adding in the price this exceeds expectations for a nice development board for the esp module.
________________________________
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

lasniko, 2020-01-10:
It clearly states the problem:

> exec /Users/mattpackwood/Library/Arduino15/packages/esp8266/tools/python3/3.7.2-post1/python3: no such file or directory

check your library structure

mattpackwood, 2020-01-10:
Hi @lasniko,
There is a file there...

lrwxr-xr-x  1 mattpackwood  staff  22 Dec 17 17:03 /Users/mattpackwood/Library/Arduino15/packages/esp8266/tools/python3/3.7.2-post1/python3 -> /usr/local/bin/python3

And the target is there, am I missing something?

mattpackwood, 2022-04-30:
Closed as no longer needed

Closed 2022-04-30.

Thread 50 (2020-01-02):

Console log not showing anything in Serial (COM port)

Dacesilian, 2020-01-02:
I'm trying to debug my program (badgy connected with USB), so I'm using this in `setup()` method:
```
Serial.begin(115200);
Serial.println("Setup");
display.init(115200);
```
But nothing is showing in terminal (only unreadable characters on boot).

Is Serial supported? Is speed 115200 okay? I've tried 9600 as well, but the same result.
When I open Tools -> Serial monitor (in Arduino IDE), badgy does not restart (as other devices do).

I'm using latest revision 2C.

Thanks.

sqfmi, 2020-01-02:
If you call display.init with a baud rate, it will try to initialize the Serial port again. Try just calling display.init() without a parameter. Serial is supported and 115200 should be fine.

Dacesilian, 2020-01-03:
Yes, I've excluded Serial.begin, as it is defined also in display.init(115200), but no text in console.

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

There was a readable text in console when connecting to WiFi, but my Serial.println is beeing ignored.

Dacesilian, 2020-01-03:
I've made a few tests and my observation is that console is fine with this code:

```
#include <GxEPD.h>
#include <GxGDEW029T5/GxGDEW029T5.h>
#include <GxIO/GxIO_SPI/GxIO_SPI.h>
#include <GxIO/GxIO.h>

GxIO_Class io(SPI, SS, 0, 2);
GxEPD_Class display(io); // default selection of D4, D2

void setup() {
  display.init(115200); // enable diagnostic output on Serial
  display.setRotation(3);
  Serial.println("Setup");
  Serial.print("..... :) .....");
  Serial.println();

  /*pinMode(1, INPUT_PULLUP); //down
    pinMode(3, INPUT_PULLUP); //left
    pinMode(5, INPUT_PULLUP); //center
    pinMode(12, INPUT_PULLUP); //right
    pinMode(10, INPUT_PULLUP); //up*/

  Serial.println("Setup done, yeah");
}
```
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

But when I enable pinMode lines, it won't show anything (even not timestamp in console):
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

chunkysteveo, 2020-01-03:
Ahh yes. The button is using the TX/RX pins. When you enable them, they are inputs, so no serial protocol output. I am sure I saw in some readme that you can't use serial output if using buttons - a vague memory I think??!

Steve

chunkysteveo, 2020-01-03:
The shared pins with TX/RX for the buttons is a limitation of the ESP8266 module and the fact the paper display needs so many pins to operate. It's either use serial output, or use buttons, not both.

chunkysteveo, 2020-01-03:
Found it - [https://github.com/sqfmi/badgy/issues/27#issuecomment-434373427](https://github.com/sqfmi/badgy/issues/27#issuecomment-434373427)

Dacesilian, 2020-01-03:
Thanks, it's clear now. It's sad.

Closed 2020-01-03.

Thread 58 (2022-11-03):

Esphome support?

jlongman, 2022-11-03:
Is badgy supported by esphome? Does anyone have config files if so?

@chunkysteveo you tagged a post with `esphome` [here](https://www.instagram.com/p/CgJeIZorzWx/)

The waveshare eink displays seem similar and closest, but different enough it seemed worth asking.

(Rev 2A if it matters)

chunkysteveo, 2022-11-04:
It is "supported" by ESPhome, yes.... depending on what you want to do with it...?!

You can use the ePaper screen (with partial refresh), and the 5-way switch. Accessing the onboard (ESP8266) as a status light seemed to cause issues, so I don't include that.

The ADC can also be included to measure the voltage level of the battery. But be aware the voltage divider used isn't right for a lipo battery.

There's a lot of pins used on the ESP8266 which tend to interfere with the OTA process by some line going low (I think?!), so I also include the "Safe mode reboot" switch, which seems allows for 100% guarantee upload (weeks of troubleshooting and testing!).

Do you have a specific example you'd like to set the Badgy up with, I can post an example YAML config?

chunkysteveo, 2022-11-04:
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

Here's two examples I have using Badgy and Home Assistant using ESPHome. The buttons aren't really used, but they could be to move between pages of content as an example.

chunkysteveo, 2022-11-04:
> @chunkysteveo you tagged a post with `esphome` [here](https://www.instagram.com/p/CgJeIZorzWx/)

Yeah, that example was also another version I had - before I updated it to the hourly/daily forecast one seen above. Those "weather" examples use a custom sensor within Home Assistant to format a bunch of other sensors into a simple text sensor that the Badgy can process and display.

jlongman, 2022-11-04:
Amazing! I’m interested in both of those, yes, and I also have a co2 monitor that I might do on its own in as- large-as-possible text. Getting the switches going might be interesting to flip between them, later, but as I have two of them I can start without it.

chunkysteveo, 2022-11-06:
Let me put a 'hello world' config yaml file up here for you to start on, which should give you some good pointers and a good base... how OK are you with ESPHome and HA?

jlongman, 2022-11-06:
A ‘hello world’ would help a lot, thanks!

Okay with esphome, I’ve put some basic sonoff switches, a co2 meter together; and competent with HA, I’ve wrestled and won with templates, etc.

chunkysteveo, 2022-11-07:
Not had any time to gather all my scripts and info together, but below is a quick and dirty "hello world" which should get you working as a proof of concept:

In HA, you will need weather.home (Met.no weather service), binary_sensor.door_sensor_back_door_contact (a binary sensor such as a door sensor),  sensor.multisensor_garage_temperature (a temperature sensor of some sort), binary_sensor.multisensor_garage_motion (a motion sensor binary sensor such as a PIR sensor. This is to blank the screen if no one is present to save on the epaper life, comment out the if else statement if you want it to always be on), and you will need to download and add some fonts to the ESPHome directory (fonts/materialdesignicons-webfont.ttf, fonts/materialdesignicons-webfont-6.9.96.ttf (I need to combine these two MDI calls into one (lazy!), feel free to fix!), fonts/Roboto-Bold.ttf, fonts/Roboto-Regular.ttf)

Hopefully the below will give you some ideas and paths to explore. The end result will be a vertical Badgy with two temperature readings, a weather cloud/sun icon from Met.no service, and a CLOSED/OPEN and door icon at the bottom, along with the update time, battery icon, and wifi range icon. This is a mis-match of a bunch of versions I have running, so it's cut back from what I run, but has a lot of things in there that I have learned..... Use the Safe Restart button if you are having issues OTA updates to Badgy.

```
substitutions:
  display_name: 'EPaper Display Badgy 01'
  device_description: 'EPaper Display Badgy 01. The White one!'
  friendly_name: 'EPaper Display Badgy 01'
  device_name: epaper-display-01
  node_name: epaper_display_01

globals:
  - id: data_updated
    type: bool
    restore_value: no
    initial_value: 'false'
  - id: initial_data_received
    type: bool
    restore_value: no
    initial_value: 'false'

esphome:
  name: ${device_name}
  comment: ${device_description}
  on_boot:
    - priority: 200.0
      then:
        - component.update: epaper
    - priority: 800.0
      then:
        - component.update: ${node_name}_uptime_raw
        - component.update: wifisignal

esp8266:
  board: nodemcuv2

# Enable logging
logger:
  # level: debug

# Enable Home Assistant API
api:

ota:
  password: !secret ota_password
  num_attempts: 5

wifi:
  ssid: !secret wifi_ssid
  password: !secret wifi_password

  # Enable fallback hotspot (captive portal) in case wifi connection fails
  ap:
    ssid: "Epaper-Display-01"
    password: "PdfmXwsyIhdgEjsxnf"

captive_portal:

time:
  - platform: homeassistant
    id: homeassistant_time

#light:
#  - platform: status_led
#    name: ${display_name} Onboard LED
#    pin:
#      number: GPIO2
#      inverted: true

text_sensor:
  - platform: wifi_info
    ip_address:
      name: ${display_name} IP Address
    ssid:
      name: ${display_name} Connected SSID
    bssid:
      name: ${display_name} Connected BSSID
  - platform: template
    name: ${friendly_name} Uptime
    id: ${node_name}_uptime
    icon: mdi:clock-start

  - platform: homeassistant
    name: forecast
    id: weather_forecast_today
    entity_id: weather.home
    internal: true

binary_sensor:
  - platform: status
    name: ${display_name} Status

  - platform: gpio
    pin:
      number: GPIO3
      mode: INPUT_PULLUP
      inverted: true
    name: ${display_name} SW LEFT
    filters:
      - delayed_on: 10ms
  - platform: gpio
    pin:
      number: GPIO1
      mode: INPUT_PULLUP
      inverted: true
    name: ${display_name} SW DOWN
    filters:
      - delayed_on: 10ms
  - platform: gpio
    pin:
      number: GPIO10
      mode: INPUT_PULLUP
      inverted: true
    name: ${display_name} SW UP
    filters:
      - delayed_on: 10ms
  - platform: gpio
    pin:
      number: GPIO12
      mode: INPUT_PULLUP
      inverted: true
    name: ${display_name} SW RIGHT
    filters:
      - delayed_on: 10ms
  - platform: gpio
    pin:
      number: GPIO5
      mode: INPUT_PULLUP
      inverted: true
    name: ${display_name} SW CENTRE
    filters:
      - delayed_on: 10ms
  - platform: homeassistant
    id: door_backdoor
    entity_id: binary_sensor.door_sensor_back_door_contact
    internal: true
    on_state:
      then:
        - component.update: epaper
  - platform: homeassistant
    id: multisensor_garage_motion_sensor
    entity_id: binary_sensor.multisensor_garage_motion
    internal: true
    on_state:
      then:
      - component.update: epaper
sensor:
  - platform: adc
    pin: A0
    #attenuation: auto
    name: ${display_name} ADC Voltage RAW
    id: li_ion_voltage_raw
    update_interval: 10s
    entity_category: diagnostic
    unit_of_measurement: "V"
    state_class: measurement
    device_class: voltage
    on_raw_value:
      then:
        - sensor.template.publish:
            id: li_ion_voltage
            state: !lambda |-
             return ((id(li_ion_voltage_raw).state*(314000+100000)) / 100000);
  - platform: template
    name: ${display_name} Battery Voltage
    id: li_ion_voltage
    #update_interval: 60s
    accuracy_decimals: 2
    entity_category: diagnostic
    unit_of_measurement: "V"
    device_class: voltage
    state_class: measurement
  - platform: template
    name: ${display_name} Battery Percentage
    id: li_ion_voltage_percentage
    unit_of_measurement: '%'
    update_interval: 12s
    entity_category: diagnostic
    accuracy_decimals: 0
    device_class: battery
    state_class: measurement
    lambda: |-
      return (((id(li_ion_voltage).state - 3) /1.14) * 100.00);
  - platform: wifi_signal
    name: ${display_name} WiFi Singal Strength
    id: wifisignal
    update_interval: 120s
  - platform: uptime
    name: "${friendly_name} Uptime Sensor"
    id: ${node_name}_uptime_raw
    update_interval: 60s
    on_raw_value:
      then:
        - logger.log:
            format: "Raw Value of Uptime sensor: %f, %f"
            args: ['id(${node_name}_uptime_raw).raw_state', 'id(${node_name}_uptime_raw).state']
            level: INFO
        - text_sensor.template.publish:
            id: ${node_name}_uptime
            state: !lambda |-
              int seconds = round(id(${node_name}_uptime_raw).raw_state);
              int days = seconds / (24 * 3600);
              seconds = seconds % (24 * 3600);
              int hours = seconds / 3600;
              seconds = seconds % 3600;
              int minutes = seconds /  60;
              seconds = seconds % 60;
              return (
                (days ? String(days) + "d " : "") +
                (hours ? String(hours) + "h " : "") +
                (minutes ? String(minutes) + "m " : "") +
                (String(seconds) + "s")
              ).c_str();

  - platform: homeassistant
    id: temp_garage
    entity_id: sensor.multisensor_garage_temperature
    internal: true
    on_value:
      then:
      - component.update: epaper
  - platform: homeassistant
    id: temp_solar_weather
    #entity_id: sensor.solar_weather_station_temperature
    entity_id: sensor.weather_home_temperature
    internal: true
    on_value:
      then:
      - component.update: epaper

button:
  - platform: restart
    name: ${display_name} restart
  - platform: safe_mode
    name: "${display_name} Restart (Safe Mode)"
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
jlongman, 2022-11-12:
Finally some time to get back to this, and preliminary results are good!

First attempts I was seeing nothing but either I watching the logs wirelessly prevents it from displaying or maybe I had `update_interval` too low or wasn't patient enough.

Now that I've got the basics I'll look at getting my CO2 levels in, thanks muchly!

chunkysteveo, 2022-11-13:
Ahhh - i wondered when you'd look at this. Good to hear it's working. I have similar results with blank screens, reboots etc. Not sure if it's the device wiring or the code, but it's not the most stable ePaper screen for HA.

Enjoy tinkering with the YAML! Check out https://github.com/Madelena/esphome-weatherman-dashboard for some good inspiration too. And there are a bunch of epaper esphome projects to borrow ideas from!

jlongman, 2023-12-22:
BTW, I'd given up on it for a while and checked in again and its working brilliantly now!  I think something in esphome improved more than any change I did.  Now I have to find the other one I've misplaced!

Showing:
- time
- indoor temp
- outdoor temp
- co2
- status of front and back doors
- back door on right, front door on left
- last update time and wifi strength.

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

chunkysteveo, 2023-12-22:
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

Haha! Looking awesome!!! Glad it is working for you. Mine has lived on my wall ever since with all sorts of temps and door icons!

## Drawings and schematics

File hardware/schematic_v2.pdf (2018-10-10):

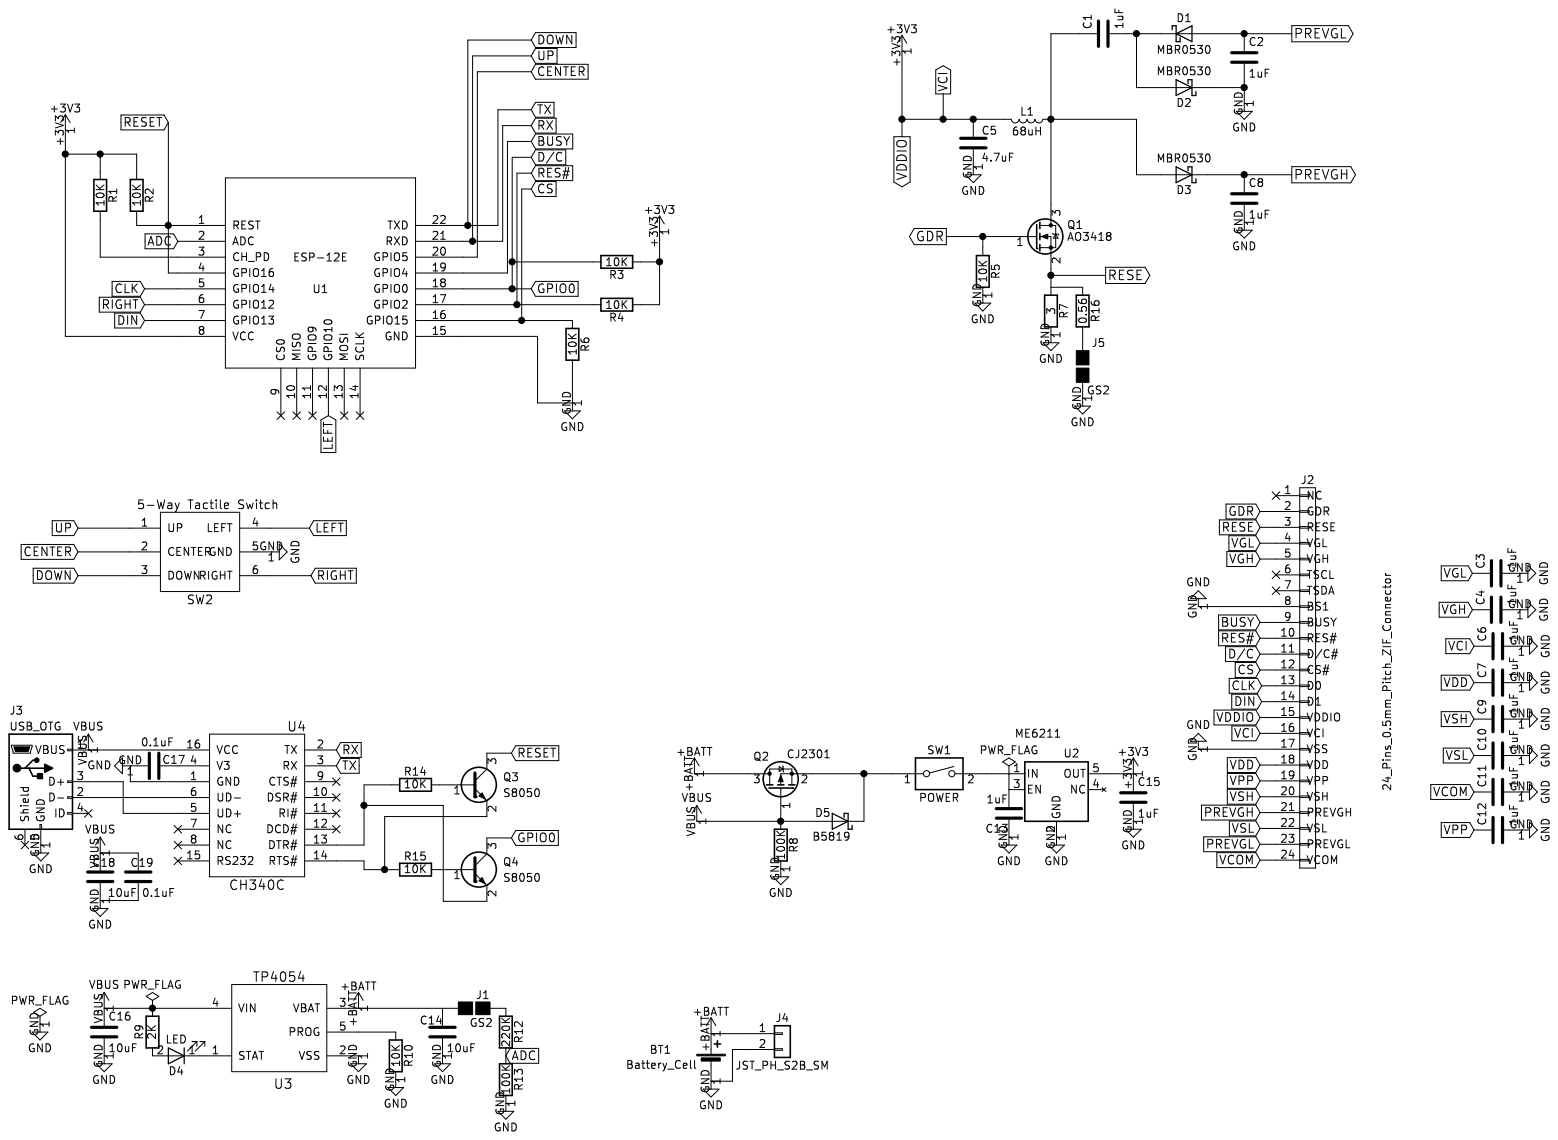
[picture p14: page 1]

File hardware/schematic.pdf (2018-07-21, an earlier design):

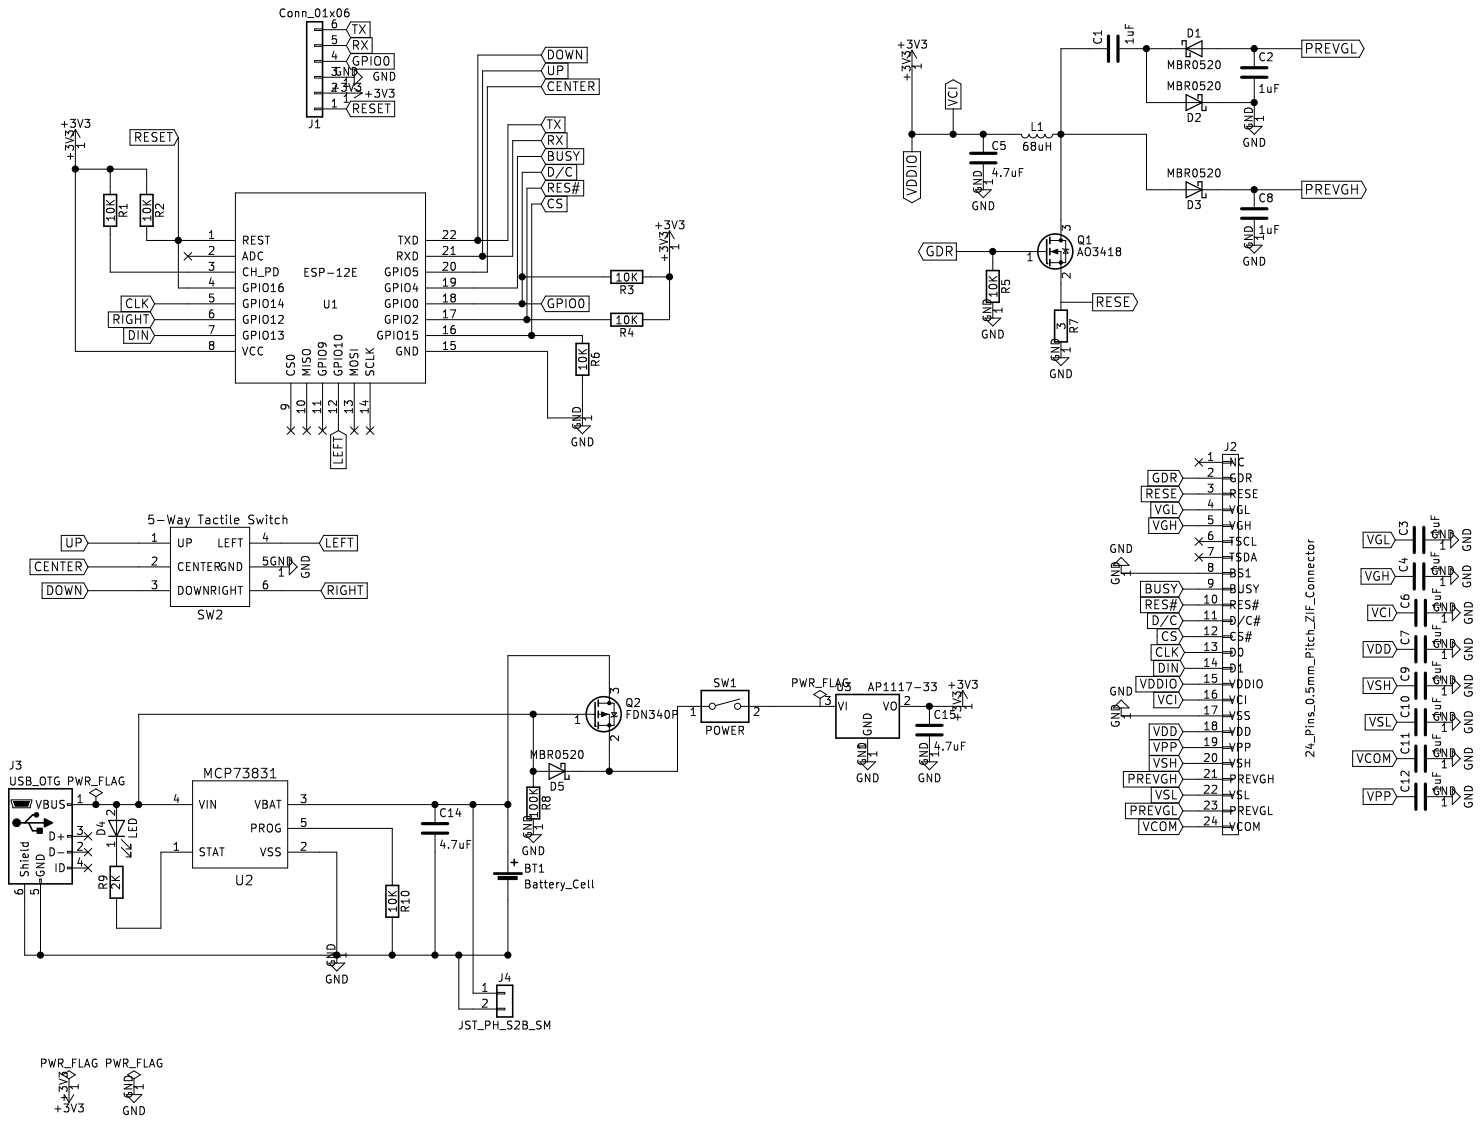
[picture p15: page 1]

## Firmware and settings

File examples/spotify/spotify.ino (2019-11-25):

 /* e-paper display lib */
#include <GxEPD.h>
//Use the GxGDEW029T5 class if you have Badgy Rev 2C. Make sure you are on GxEPD 3.05 or above
#include <GxGDEW029T5/GxGDEW029T5.h>
//Use the GxGDEH029A1 class if you have anything older
//#include <GxGDEH029A1/GxGDEH029A1.h>
#include <GxIO/GxIO_SPI/GxIO_SPI.h>
#include <GxIO/GxIO.h>
/* include any other fonts you want to use https://github.com/adafruit/Adafruit-GFX-Library */
#include <Fonts/FreeMonoBold9pt7b.h>
#include <Fonts/FreeMonoBold12pt7b.h>
/* WiFi  libs*/
#include <ESP8266WiFi.h>
#include <WiFiClientSecure.h>
#include <ESP8266mDNS.h>
#include <ESP8266WebServer.h>
#include <ESP8266HTTPUpdateServer.h>
#include <WiFiManager.h>
#include <ArduinoJson.h>
#include <FS.h>

#include "buttons.h"

/* Always include the update server, or else you won't be able to do OTA updates! */
/**/const int port = 8888;
/**/ESP8266WebServer httpServer(port);
/**/ESP8266HTTPUpdateServer httpUpdater;
/*                                                                                */

/* Configure pins for display */
GxIO_Class io(SPI, SS, 0, 2);
GxEPD_Class display(io); // default selection of D4, D2

/* A single byte is used to store the button states for debouncing */
byte buttonState = 0;
byte lastButtonState = 0;   //the previous reading from the input pin
unsigned long lastDebounceTime = 0;  //the last time the output pin was toggled
unsigned long debounceDelay = 50;    //the debounce time

unsigned long updateInterval = 800;
unsigned long lastUpdate = 0;


/* Spotify API endpoints */
String apiHost = "api.spotify.com";
String authHost = "accounts.spotify.com";
String currentPlayerAPI = "/v1/me/player/";
String tokenAPI = "/api/token";
const int httpsPort = 443;
String MDNSName = "badgy-spotify";

/* Spotify app credentials, go to https://developer.spotify.com to setup */
String clientId = "YOUR_CLIENT_ID";
String clientSecret = "YOUR_CLIENT_SECRET";
String token = "";
bool isPlaying = false;

void setup(){
  if(!SPIFFS.begin()){
    showText("Formatting FS...");
    SPIFFS.format();
    showText("FS format complete!");
    SPIFFS.begin();
  }

  display.init();

  pinMode(1,INPUT_PULLUP); //down
  pinMode(3,INPUT_PULLUP); //left
  pinMode(5,INPUT_PULLUP); //center
  pinMode(12,INPUT_PULLUP); //right
  pinMode(10,INPUT_PULLUP); //up

  /* WiFi Manager automatically connects using the saved credentials, if that fails it will go into AP mode */
  WiFiManager wifiManager;
  wifiManager.setAPCallback(configModeCallback);
  wifiManager.autoConnect("Badgy AP");

  /* Once connected to WiFi, startup the OTA update server if the center button is held on boot */
  if(digitalRead(5)  == 0){
    httpUpdater.setup(&httpServer);
    httpServer.begin();
    showIP();
    while(1){
      httpServer.handleClient();
    }
  }

  getPlayback();
  delay(1000);
}

void loop(){
  byte reading =  (digitalRead(1)  == 0 ? 0 : (1<<0)) | //down
                  (digitalRead(3)  == 0 ? 0 : (1<<1)) | //left
                  (digitalRead(5)  == 0 ? 0 : (1<<2)) | //center
                  (digitalRead(12) == 0 ? 0 : (1<<3)) | //right
                  (digitalRead(10) == 0 ? 0 : (1<<4));  //up

  if(reading != lastButtonState){
    lastDebounceTime = millis();
  }
  if((millis() - lastDebounceTime) > debounceDelay){
    if(reading != buttonState){
      buttonState = reading;
      for(int i=0; i<5; i++){
        if(bitRead(buttonState, i) == 0){
          switch(i){
            case 0:
              //do something when the user presses down
              showText("You pressed the down button!");
              break;
            case 1:
              //do something when the user presses left
              //showText("You pressed the left button!");
              controlPlayer(1);
              display.drawBitmap(prev, 73, 84, 32, 32, GxEPD_BLACK);
              break;
            case 2:
              //do something when the user presses center
              //showText("You pressed the center button!");
              controlPlayer(2);
              break;
            case 3:
              //do something when the user presses right
              //showText("You pressed the right button!");
              controlPlayer(0);
              display.drawBitmap(next, 193, 84, 32, 32, GxEPD_BLACK);
              break;
            case 4:
              //do something when the user presses up
              showText("You pressed the up button!");
              break;
            default:
              break;
          }
        }
      }
    }
  }
  lastButtonState = reading;

  if (millis() - lastUpdate > updateInterval){
    getPlayback();
    lastUpdate = millis();
  }

}

void configModeCallback (WiFiManager *myWiFiManager){
  display.setRotation(3); //even = portrait, odd = landscape
  display.fillScreen(GxEPD_WHITE);
  const GFXfont* f = &FreeMonoBold9pt7b ;
  display.setTextColor(GxEPD_BLACK);
  display.setFont(f);
  display.setCursor(0,50);
  display.println("Connect to Badgy AP");
  display.println("to setup your WiFi!");
  display.update();
}

void showIP(){
  display.setRotation(3); //even = portrait, odd = landscape
  display.fillScreen(GxEPD_WHITE);
  const GFXfont* f = &FreeMonoBold9pt7b ;
  display.setTextColor(GxEPD_BLACK);
  display.setFont(f);
  display.setCursor(0,10);

  String url = WiFi.localIP().toString() + ":"+String(port)+"/update";
  byte charArraySize = url.length() + 1;
  char urlCharArray[charArraySize];
  url.toCharArray(urlCharArray, charArraySize);

  display.println("You are now connected!");
  display.println("");
  display.println("Go to:");
  display.println(urlCharArray);
  display.println("to upload a new sketch.");
  display.update();
}

void showText(char *text)
{
  display.setRotation(3); //even = portrait, odd = landscape
  display.fillScreen(GxEPD_WHITE);
  const GFXfont* f = &FreeMonoBold9pt7b ;
  display.setTextColor(GxEPD_BLACK);
  display.setFont(f);
  display.setCursor(10,70);
  display.println(text);
  display.update();
}

String getToken(){

  /* Check if refresh token exists*/
  String refreshToken = "";
  showText("Loading config");
  File f = SPIFFS.open("/refresh.token", "r");
  if(!f){
    showText("Failed to open config file");
  }else{
    while(f.available()) {
        //Lets read line by line from the file
        refreshToken = f.readStringUntil('\r');
        //Serial.printf("Refresh Token: %s\n", refreshToken.c_str());
        f.close();
    }
  }

  String authCode = "";
  if(refreshToken == ""){
  /********************************************************************************/
  /* 1. Start MDNS service to provide callback URL for authorizing Spotify access */
  /********************************************************************************/
  if(!MDNS.begin(MDNSName.c_str())){
    //Serial.println("Error setting up MDNS responder!");
    while(1){
      delay(1000);
    }
  }

  /**************************************************************************************************************/
  /* 2. Create portal to authorize the Badgy Spotify Remote application with Spotify, get an authorization code */
  /**************************************************************************************************************/
  ESP8266WebServer server;

  /* Server route handlers */
  server.on("/", [&server](){
    server.sendHeader("Location", String("https://accounts.spotify.com/authorize/?client_id="
      + clientId
      + "&response_type=code&redirect_uri="
      + "http://" + MDNSName + ".local/callback/"
      + "&scope=user-read-playback-state%20user-modify-playback-state"), true);
    server.send(302, "text/plain", "");
  });
  server.on("/callback/",[&authCode,&server](){
    if(server.hasArg("code")){
      authCode = server.arg("code");
      server.send(200, "text/html", "Authorization Success!");
    }else{
      server.send(500, "text/plain", "Error Getting Authorization Code!");
    }
  });

  /* Start server */
  server.begin();
  MDNS.addService("http", "tcp", 80);

  /* Handle server requests until user has authorized */
  while(authCode == ""){
    server.handleClient();
    yield();
  }

  }//refreshToken == ""
  /**************************************************************************************************************/
  /* 3. Use authorization code from previous step to obtain an API token                                        */
  /**************************************************************************************************************/

  /* Initiate HTTPS connection to Spotify's authentication endpoint  */
  WiFiClientSecure client;
  if(!client.connect(authHost.c_str(), httpsPort)){
    showText("Connection Failed!");
  }

  /* There are 2 grant types, authorization_code for a new token, and refresh_token if you're refreshing */
  String grantType    = (refreshToken == "") ? "authorization_code" : "refresh_token";
  String codeType    = (refreshToken == "") ? "code" : "refresh_token";
  authCode = (refreshToken == "") ? authCode : refreshToken;
  /* HTTPS request body */
  String requestBody  = "grant_type="       + grantType       +
                        "&"+ codeType +"="            + authCode        +
                        "&client_id="       + clientId        +
                        "&client_secret="   + clientSecret    +
                        "&redirect_uri="    + "http%3A%2F%2F" + MDNSName + ".local%2Fcallback%2F";
  /* HTTPS request string */
  String httpsString   = "POST "             + tokenAPI        + " "
                        "HTTP/1.1\r\n"      + "Host: "        + authHost.c_str()  + "\r\n"  +
                        "Content-Length: "  + String(requestBody.length())        + "\r\n"  +
                        "Content-Type: application/x-www-form-urlencoded\r\n"     +
                        "Connection: close\r\n\r\n" + requestBody;
  /* Send request */
  //Serial.println(httpsString);
  client.print(httpsString);

  /* Check HTTP status response */
  char status[32] = {0};
  client.readBytesUntil('\r', status, sizeof(status));
  //Serial.println(status);
  if(strcmp(status, "HTTP/1.1 200 OK") != 0){
    showText("HTTP Status Error!");
  }

  /* Find the end of headers */
  char endOfHeaders[] = "\r\n\r\n";
  if (!client.find(endOfHeaders)) {
    showText("Invalid Response...");
  }

  /* Start parsing the JSON in the response body */
  DynamicJsonBuffer jsonBuffer;
  JsonObject& root = jsonBuffer.parseObject(client);
  if(!root.success()){
    showText("JSON parsing failed!");
  }

  /* We have our tokens!  */
  String token = root["access_token"];
  String newRefreshToken = root["refresh_token"];

  /* Save the refresh token */
  if(newRefreshToken != ""){
    File s = SPIFFS.open("/refresh.token", "w+");
    if (!s) {
      showText("Failed to open config file");
    }
    s.println(newRefreshToken);
    s.close();
  }
  /**/
  //Serial.println(token);
  return token;
}

void controlPlayer(int control){

  String command = "";
  String method = "";
  if(control == 0){
    command = "next";
    method = "POST ";
  }
  else if(control == 1){
    command = "previous";
    method = "POST ";
  }
  else if(control == 2){
     command = isPlaying ? "pause" : "play";
     method = "PUT ";
  }else{
    return;
  }

  if(token == ""){
    token = getToken();
  }
  /* Construct request string and send */
  WiFiClientSecure client;
  if(!client.connect(apiHost.c_str(), httpsPort)){
    showText("Connection Failed!");
  }

  String request = "" + method + currentPlayerAPI + command + " HTTP/1.1\r\n" +
                   "Host: " + apiHost + "\r\n" +
                   "Authorization: Bearer " + token + "\r\n" +
                   "Content-Length: 0\r\n" +
                   "Connection: close\r\n\r\n";
  client.print(request);

  /* Catch response errors */
  char status[32] = {0};
  client.readBytesUntil('\r', status, sizeof(status));
  if(strcmp(status, "HTTP/1.1 200 OK") == 0){
    //showText("Spotify Player Active");
  }
  else if(strcmp(status, "HTTP/1.1 204 No Content") == 0){
    //showText("Spotify Player Inactive");
    return;
  }else{
    showText(status);
    return;
  }

  char endOfHeaders[] = "\r\n\r\n";
  if (!client.find(endOfHeaders)) {
    showText("Invalid Response...");
    return;
  }

  /* Parse JSON response*/
  DynamicJsonBuffer jsonBuffer; //buffer for JSON response
  JsonObject& root = jsonBuffer.parseObject(client);
  if(!root.success()){
    showText("JSON parsing failed!");
    return;
  }
}

void getPlayback(){

  if(token == ""){
    token = getToken();
  }

  /* Construct request string and send */
  WiFiClientSecure client;
  if(!client.connect(apiHost.c_str(), httpsPort)){
    showText("Connection Failed!");
  }

  String request = "GET " + currentPlayerAPI + " HTTP/1.1\r\n" +
                   "Host: " + apiHost + "\r\n" +
                   "Authorization: Bearer " + token + "\r\n" +
                   "Connection: close\r\n\r\n";
  client.print(request);

  /* Catch response errors */
  char status[32] = {0};
  client.readBytesUntil('\r', status, sizeof(status));
  if(strcmp(status, "HTTP/1.1 200 OK") == 0){
    //showText("Spotify Player Active");
  }
  else if(strcmp(status, "HTTP/1.1 204 No Content") == 0){
    showText("Spotify Player Inactive");
    return;
  }else{
    showText("Unexpected Response...");
    return;
  }

  char endOfHeaders[] = "\r\n\r\n";
  if (!client.find(endOfHeaders)) {
    showText("Invalid Response...");
    return;
  }

  /* Parse JSON response*/
  DynamicJsonBuffer jsonBuffer; //buffer for JSON response
  JsonObject& root = jsonBuffer.parseObject(client);
  if(!root.success()){
    showText("JSON parsing failed!");
    return;
  }

  /* Print current track details on display */
  String currentTrack = root["item"]["name"];
  String currentAlbum = root["item"]["album"]["name"];
  String currentArtist = root["item"]["artists"][0]["name"];
  isPlaying = root["is_playing"] == "true";


  /* Print current track details on display */
  long currentProgress = root["progress_ms"];
  long currentDuration = root["item"]["duration_ms"];
  int minutes = (currentProgress/1000) / 60;
  int seconds = (currentProgress/1000) % 60;
  int location = ((currentProgress * (296 - 20)) / currentDuration) + 10;

 // Serial.println(currentTrack);
 // Serial.println(currentAlbum);
 // Serial.println(currentArtist);

  display.setRotation(3); //even = portrait, odd = landscape
  display.fillScreen(GxEPD_WHITE);
  const GFXfont* f = &FreeMonoBold12pt7b;
  display.setTextColor(GxEPD_BLACK);
  display.setFont(f);
  display.setCursor(0,20);
  display.println(currentTrack);
  const GFXfont* g = &FreeMonoBold9pt7b;
  display.setTextColor(GxEPD_BLACK);
  display.setFont(g);
  display.print(currentAlbum);
  display.print(" - ");
  display.println(currentArtist);

  //display.setCursor(10,60);
  // display.print(minutes);
  //display.print(":");
  //display.print(seconds);
  display.fillRect(10, 70, (296 - 20), 5, GxEPD_BLACK);
  display.fillCircle(location, 72, 5, GxEPD_BLACK);
  //display.update();
  if(isPlaying){
    display.drawBitmap(play, 133, 84, 32, 32, GxEPD_WHITE);
  }else{
    display.drawBitmap(pause, 133, 84, 32, 32, GxEPD_WHITE);
  }
  display.drawBitmap(prev, 73, 84, 32, 32, GxEPD_WHITE);
  display.drawBitmap(next, 193, 84, 32, 32, GxEPD_WHITE);
  display.updateWindow(0, 0, GxEPD_WIDTH, GxEPD_HEIGHT, false); //last param is using rotation
}

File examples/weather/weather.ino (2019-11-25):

/* e-paper display lib */
#include <GxEPD.h>
//Use the GxGDEW029T5 class if you have Badgy Rev 2C. Make sure you are on GxEPD 3.05 or above
#include <GxGDEW029T5/GxGDEW029T5.h>
//Use the GxGDEH029A1 class if you have anything older
//#include <GxGDEH029A1/GxGDEH029A1.h>
#include <GxIO/GxIO_SPI/GxIO_SPI.h>
#include <GxIO/GxIO.h>
/* include any other fonts you want to use https://github.com/adafruit/Adafruit-GFX-Library */
#include <Fonts/FreeMonoBold9pt7b.h>
#include <Fonts/FreeMonoBold18pt7b.h>
#include "icons.h"
/* WiFi  libs*/
#include <ESP8266WiFi.h>
#include <WiFiClient.h>
#include <DNSServer.h>
#include <ESP8266WebServer.h>
#include <ESP8266HTTPUpdateServer.h>
#include <WiFiManager.h>
/* Util libs */
#include <Time.h>
#include <TimeLib.h>
#include <ArduinoJson.h>

const char* host = "api.openweathermap.org";
const char* API_KEY = "YOUR_API_KEY"; //Your API key https://home.openweathermap.org/
const char* CITY_ID = "5128581"; //City ID https://openweathermap.org/find
const int time_zone = -5; // e.g. UTC-05:00 = -5
const boolean IS_METRIC_UNITS = true;

/* Always include the update server, or else you won't be able to do OTA updates! */
/**/const int port = 8888;
/**/ESP8266WebServer httpServer(port);
/**/ESP8266HTTPUpdateServer httpUpdater;
/*                                                                                */

/* Configure pins for display */
GxIO_Class io(SPI, SS, 0, 2);
GxEPD_Class display(io); // default selection of D4, D2

void setup()
{  
  display.init();
  
  pinMode(1,INPUT_PULLUP); //down
  pinMode(3,INPUT_PULLUP); //left
  pinMode(5,INPUT_PULLUP); //center
  pinMode(12,INPUT_PULLUP); //right
  pinMode(10,INPUT_PULLUP); //up

  /* WiFi Manager automatically connects using the saved credentials, if that fails it will go into AP mode */
  WiFiManager wifiManager;
  wifiManager.setAPCallback(configModeCallback);
  wifiManager.autoConnect("Badgy AP");

  if(digitalRead(5) == 0) {
    /* Once connected to WiFi, startup the OTA update server if the center button is held on boot */
    httpUpdater.setup(&httpServer);
    httpServer.begin();
    showIP();
    while(1){
      httpServer.handleClient();
    }
  }
  if (getWeatherData() && getForecastData()) { 
    // Success in getting weather an forecast data.  Sleep for an 3600e6 microseconds -- an hour.
    ESP.deepSleep(3600e6, WAKE_RF_DEFAULT); 
  } else {
    // A failure of some sort.  Wait for 5 seconds and then retry.
    ESP.deepSleep(5e6, WAKE_RF_DEFAULT); 
  }
}

void loop()
{  
  // loop is never executed in this program as the setup does all the work
  // then puts the ESP into a deep sleep which will cause a reset at the
  // conclusion which runs setup again.
}

void configModeCallback (WiFiManager *myWiFiManager){
  display.setRotation(3); //even = portrait, odd = landscape
  display.fillScreen(GxEPD_WHITE);
  const GFXfont* f = &FreeMonoBold9pt7b ;
  display.setTextColor(GxEPD_BLACK);
  display.setFont(f);
  display.setCursor(0,50);
  display.println("Connect to Badgy AP");
  display.println("to setup your WiFi!");
  display.update();  
}

void showText(char *text)
{
  display.setRotation(3); //even = portrait, odd = landscape
  display.fillScreen(GxEPD_WHITE);
  const GFXfont* f = &FreeMonoBold9pt7b ;
  display.setTextColor(GxEPD_BLACK);
  display.setFont(f);
  display.setCursor(10,70);
  display.println(text);
  display.println("Auto-retry in 5 seconds.");
  display.update();
}

void showIP(){
  display.setRotation(3); //even = portrait, odd = landscape
  display.fillScreen(GxEPD_WHITE);
  const GFXfont* f = &FreeMonoBold9pt7b ;
  display.setTextColor(GxEPD_BLACK);
  display.setFont(f);
  display.setCursor(0,10);

  String url = WiFi.localIP().toString() + ":"+String(port)+"/update";
  byte charArraySize = url.length() + 1;
  char urlCharArray[charArraySize];
  url.toCharArray(urlCharArray, charArraySize);

  display.println("You are now connected!");
  display.println("");  
  display.println("Go to:");
  display.println(urlCharArray);
  display.println("to upload a new sketch.");
  display.update();  
}

bool getWeatherData()
{
  String type= "weather";
  String url = "/data/2.5/"+type+"?id="+CITY_ID+"&units="+getUnitsString()+"&appid="+API_KEY;

  // Use WiFiClient class to create TCP connections
  WiFiClient client;
  const int httpPort = 80;
  if (!client.connect(host, httpPort)) {
    showText("connection failed");
    return false;
  }
  
  // This will send the request to the server
  client.print(String("GET ") + url + " HTTP/1.1\r\n" +
               "Host: " + host + "\r\n" + 
               "Connection: close\r\n\r\n");
  unsigned long timeout = millis();
  while (client.available() == 0) {
    if (millis() - timeout > 5000) {
      showText(">>> Client Timeout !");
      client.stop();
      return false;
    }
  }

  // Read response
  String city;
  float current_temp;
  int humidity;
  float temp_min;
  float temp_max;
  float wind;
  String icon_code;
  int condition;
  int time;
  
  while(client.available()){
    char status[32] = {0};
    client.readBytesUntil('\r', status, sizeof(status));
    //Serial.println(status);
    if(strcmp(status, "HTTP/1.1 200 OK") != 0){
      showText("HTTP Status Error!");
      return false;
    }

    /* Find the end of headers */
    char endOfHeaders[] = "\r\n\r\n";
    if (!client.find(endOfHeaders)) {
      showText("Invalid Response...");
      return false;
    }
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

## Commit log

2017-12-31 Added schematic
2018-07-21 updated schematic
2018-08-28 Missing 3D model for screen and 5-way button
2018-08-28 Missing 5-way switch
    Pre-release. Please use a real Badgy for the most accurate measurements.
2018-08-29 Add files via upload
    Update to 3D STEP file to include 5-way switch and a rough design of the 2.9inch e-paper according to Waveshare's datasheet on the module.
2018-10-10 Schematic for updated Badgy (white PCB)
2019-05-10 Failure handling
    Rather than wait for another hour retry the fetch after 5 seconds. Under persistent failure cases this will consume a lot more power and therefore drain the battery if being run off of a battery.
    [weather.ino]
2019-05-10 Clarity about boards and deep sleep
    Added a bit more details to hopefully help others.
2019-07-24 Moved battery details higher to avoid confusion
